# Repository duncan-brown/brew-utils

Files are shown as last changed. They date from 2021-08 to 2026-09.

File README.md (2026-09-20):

# brew-utils

Software for a homebrewery dashboard built out of Knight Rider (KITT) dash
replica hardware.

Two Raspberry Pis read temperature probes, flow meters, fermentation
controllers and a keg-monitoring database, and render all of it onto the gauges
of a replica KITT dashboard: the MPH display shows hot liquor tank temperature,
the RPM gauges show serving keezer probes, the LED bargraphs show fermenter
temperatures and how much beer is left in each keg, and the message center
captions whatever the multi-function display is currently showing.

There is a full build write-up, with photos of what every gauge means, at
[Brewery Dashboard on HomebrewTalk](https://www.homebrewtalk.com/threads/brewery-dashboard.726917/).
The physical side — power supply, relays, probes, which wire goes to which pin
on which Pi — is in [HARDWARE.md](HARDWARE.md).

## How it fits together

```
    probes, flow meters, kegs                two Raspberry Pis            KITT dash
    ─────────────────────────                ─────────────────            ─────────
    DS18B20 one-wire probes  ──────────────▶  rpints  ──── serial ────▶  tacho
    RaspberryPints (MySQL)   ──────────────▶          ──── serial ────▶  dummy3, dummy6
                                                 │
                                            GPIO │ mode
                                                 ▼
    DS18B20 one-wire probes  ──────────────▶  brewpi  ──── serial ────▶  speedo
    BrewPi Remix ◀── TiltBridge ◀── Tilt ──▶          ──── serial ────▶  message center
    flow meter relays        ◀──────────────
```

- **`rpints`** runs [RaspberryPints](https://github.com/RaspberryPints/RaspberryPints)
  for keg volume tracking, and owns the dashboard's Power/Auto/Norm/Pursuit
  buttons and the power relays for the whole dash.
- **`brewpi`** runs three instances of [BrewPi Remix](https://github.com/brewpi-remix/brewpi-tools-rmx)
  for fermentation control, which get specific-gravity readings from Tilt
  hydrometers via [TiltBridge](https://github.com/thorrak/tiltbridge).
- The two Pis coordinate over GPIO lines so that pressing Auto, Norm or Pursuit
  on one changes what the other displays and how brightly.
- Both drive the dash boards over serial using Paolo Sancono's KITT protocol.
  The dash electronics themselves are from [ideegeniali](https://www.ideegeniali.it/).

## What's in here

| Path | Status | Description |
| --- | --- | --- |
| [`kitt/`](kitt/) | **in service** | The current system. `panp/panp.py` drives the whole dashboard; `switchpod/` is the Arduino firmware for the dash keypads. See [kitt/README.md](kitt/README.md) for how it works, and [kitt/DASHBOARD.md](kitt/DASHBOARD.md) for what each gauge means. |
| [`schematics/`](schematics/) | reference | KiCad schematics of the control electronics, four sheets generated from the wiring in `HARDWARE.md`; rendered as `images/schematic-*.svg`. |
| `brewpitosmith` | utility | Converts a BrewPi Remix beer log into a CSV that BeerSmith 3 will import, thinned to one row an hour. |
| `images/` | reference | Photographs of the switch pods, the season 2 dash scan, and the `hw-*` photographs of the bench, supply box and control panel that [HARDWARE.md](HARDWARE.md) refers to. |

Two earlier efforts have been archived out of the tree. Each is tagged, so the
whole thing comes back with one command:

| Tag | What it was |
| --- | --- |
| `karr-prototype` | An attempt to rebuild the dash electronics from scratch — four ESP32s driving daisy-chained TLC5940 drivers, with a KiCad board and gerbers. Shelved in 2023 when the ideegeniali boards arrived; never ran the brewery. |
| `pi-temp-display-final` | The predecessor to the KITT dash: seven-segment LEDs multiplexed with pigpio, showing mash temperature and keezer min/max. |

```bash
git checkout karr-prototype -- karr/
```

## Credits

The parts of this system that do the actual work of running the brewery are
other people's: BrewPi Remix by [@LBussy](https://github.com/lbussy), TiltBridge
by [@Thorrak](https://github.com/thorrak), RaspberryPints by
[@RandR+](https://github.com/RandRPints), and the KITT dash boards and serial
protocol by Paolo Sancono at ideegeniali. Thanks also to @day_trippr for help
along the way.

## License

MIT — see [LICENSE](LICENSE).

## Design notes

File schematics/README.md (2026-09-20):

# Schematics

KiCad schematics of the brewery control electronics, generated from the wiring
recorded in [../HARDWARE.md](../HARDWARE.md). Four sheets, A3:

| Sheet | File | What is on it |
| --- | --- | --- |
| 1 | `sheet1-power.kicad_sch` | the supply box: 12 V supply, the three inline fuses, the latching relay and the two Pi interlocks behind the `POWER` button, both D-1012 contactors, the D-1384 fuse block, the 12→24 V converter and the buffer capacitor |
| 2 | `sheet2-rpints.kicad_sch` | rpints: PANP buttons and lamps, the 8-way relay module (flow meters and lamps), the 4-channel dash power module, the serving keezer strip and RaspberryPints Uno, the 12-way serial/one-wire strip, the right switch pod |
| 3 | `sheet3-brewpi.kicad_sch` | brewpi: relay drives, mode lines, hot-side probes, serial to the message centre and speedo, the left switch pod, and the three BrewPi Remix controllers with their heaters and glycol pumps |
| 4 | `sheet4-dash.kicad_sch` | strip 1 to the Pi buck converters, the DASH POWER block to the six dash boards, and the four PANP switches on their two 8-way strips |

Rendered copies are in [`../images/`](../images/) as `schematic-sheet*.svg`.

## How they are made

The sheets are **generated**, not drawn by hand. `ksheets.py` describes every
component and wire in Python; `kicadgen.py` turns that into KiCad's S-expression
format (version `20250114`, KiCad 9 and 10). Stock symbols such as fuses,
resistors and screw terminals are copied out of the installed KiCad libraries at
generation time; the relay modules, Pis, Unos and dash boards are simple boxes
with named terminals defined in `kicadgen.box_symbol`, which is how they present
physically.

Nets that cross sheets are global labels with the same name on each sheet, for
example `MASTER_RELAY`, `P1_+12V`, `RPINTS_GND`, `BREWPI_IO16`.

To regenerate after editing `ksheets.py`:

```bash
python3 schematics/ksheets.py schematics
```

then export and check with KiCad's command line:

```bash
K=/Applications/KiCad/KiCad.app/Contents/MacOS/kicad-cli
for f in schematics/sheet*.kicad_sch; do
  $K sch export svg -o images -e "$f"
  $K sch erc --severity-all --format report -o "${f%.kicad_sch}.erc" "$f"
done
```

All four sheets pass ERC with no errors. The remaining warnings are expected:
global labels that appear on only one sheet (they are for the reader, and for
the sheet they pair with), and the note that the home-made `brew:` symbols are
not in a configured library, which is by design since they are embedded in each
file.

## Editing in KiCad

The files open directly in KiCad's schematic editor. Edits made there are fine
for a one-off print, but they will be overwritten by the next run of
`ksheets.py`, so a lasting change belongs in the Python. The reference
designators are deliberate and match [../HARDWARE.md](../HARDWARE.md): `K1` is
the latching relay, `K2`/`K3` the interlocks, `K4`/`K5` the contactors, `K6` the
8-way module, `K7` the 4-channel dash power module, `K8` the 6-channel fermenter
module.

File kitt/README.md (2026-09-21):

# kitt

The software that drives the KITT dashboard. Two pieces:

- [`panp/panp.py`](panp/panp.py) — the daemon that runs on both Raspberry Pis
  and puts brewery data onto the dash gauges.
- [`switchpod/`](switchpod/) — Arduino firmware that reads the dash keypads.
  How a pod reaches the Pi is in [switchpod/README.md](switchpod/README.md).

PANP stands for Power / Auto / Norm / Pursuit, the four buttons on the dash.

This file is about how the software works. For what each gauge on the dash
means — KITT's labels against the brewery values behind them — see
[DASHBOARD.md](DASHBOARD.md).

## One script, two Pis

`panp.py` is installed identically on both machines and decides what it is at
startup from `socket.gethostname()`. Anything else exits with an error.

| | `rpints` | `brewpi` |
| --- | --- | --- |
| Loop class | `RPintsLoopHandler` | `BrewPiLoopHandler` |
| Reads | 6 keezer + 3 lager probes, RaspberryPints MySQL | mash + HLT probes, 3 BrewPi Remix instances |
| Drives | tacho, red dummy3, dummy6 | speedo, message center, red/green dummy3 |
| Owns | PANP buttons and lamps, dash power relays, the Hue bench and room lights | flow meter relays |
| Mode GPIO | output (tells `brewpi` the mode) | input (follows `rpints`) |

Shared between them: `read_probe_f` and the `get_temps` thread,
`BrightnessHandler`, `Bus` and `Wire` (the serial ports and the gate that
paces writes to them), `Service` (systemd
notification and shutdown), and the pin constants at the top of the file.
`main()` calls `setup_rpints` or `setup_brewpi` and then runs the loop.

## Structure

Everything slow runs in a daemon thread and communicates with the main loop
through a `Queue`. The main loop never blocks on I/O.

```
  ┌────────────────────┐
  │ get_switchpod()    │  reads /dev/switchpod, one digit per keypress
  ├────────────────────┤
  │ get_temps()        │  polls one-wire probes once a second
  ├────────────────────┤        ┌───────────┐      ┌──────────────┐
  │ get_brewpi_rmx_... │───────▶│  Queues   │─────▶│ loop_handler │────▶ serial
  └────────────────────┘        └───────────┘      │  .loop()     │      to dash
                                                   └──────────────┘
                                                    every 0.25 s
```

Each `loop()` call drains its queues with `drain(q)`, recomputes what should
be on screen, and writes it out. Queue entries are `(index, value)` tuples.

The Hue lights run the other way round: `PANPHandler` queues an on or off
request for the bench light from the button callback, the loop handler
queues one for the room lights when a right-pod key asks, and the
`HueLight.loop()` thread talks to the Hue bridge, which is in another part of
the building. A slow or absent bridge can therefore never hold up the dash.

The database is polled less often than everything else: `RPintsLoopHandler`
counts passes and only queries RaspberryPints once every `DATABASE_EVERY`
passes, which is eleven.

## The PANP modes

Pressing a PANP button on `rpints` moves power relays and flips the two GPIO
lines that `brewpi` watches, so both Pis change behaviour together.

| Mode | Dash | Message center |
| --- | --- | --- |
| **Auto** | off (relays cut power to upper and lower dash) | stays on, showing `BREWPI UP` and flow meter status |
| **Norm** | on, dimmed | captions the lower display |
| **Pursuit** | on, full brightness, switch pod lamps lit, bench light on | captions the lower display |

Leaving Auto clears every display and re-sends brightness, because the boards
were unpowered and have lost their state.

Pursuit also switches on the Hue light strip over the brewery workbench, at
full brightness and a chosen white, so there is enough light to read small
print; Norm and Auto switch it off, as does halting the Pis. Two keys on the
right switch pod, `P IND` and `EJECT R`, switch the brewery's room lights on
and off the same way. `rpints` talks to the Hue bridge's v2 API directly, from
a worker thread. It is optional and is configured by
`/usr/local/etc/panp-hue.json`, which is not in this repository because it
holds the bridge's application key; without the file nothing happens, which
is the case on `brewpi`. Setting it up, including getting a key from the
bridge, choosing the colour temperature and listing the room lights, is in
[panp/README.md](panp/README.md).

The Power button is not software at all. It triggers a latching relay that
switches the whole 12 V supply, and each Pi holds an interlock relay *open*
while it is up, taking the button out of the circuit — so nothing can be
switched off without halting both Pis first. That is `power-relay-*.service`
(opens the interlock at boot) and `power-off-*.sh` (releases it during
shutdown). The wiring is in [../HARDWARE.md](../HARDWARE.md#the-power-button).

## Switch pod buttons

Each switch pod is a resistive keypad read by an Arduino, which prints a
position 0–9 over serial; `panp.py` reads them from `/dev/switchpod` in
`get_switchpod()` and queues them for the loop handler.

Even positions are the pod's left column, odd positions the right — which is
why each handler treats `sp_val` 0/2/4/6/8 as one family and 1/3/5/7/9 as
another. The **right** pod (`rpints`) drives the tacho digits and arc: its
left column is one key per keg, showing the imperial pints left and then the
US gallons left before returning to the keezer mean, its right
column shows the three lager probes, and its last two keys switch the brewery
room lights over the Hue bridge — except that in Pursuit `P IND` cycles the
bench light's colour instead. Coming up from Auto resets the tacho to the
mean. The **left** pod (`brewpi`) selects what the lower speedo display shows
and toggles the flow meter relays. Toggling a flow meter flashes `FLOW n on` on
the message center for a second, then restores the normal caption.

Full button-by-button tables, with photographs of both pods, are in
[DASHBOARD.md](DASHBOARD.md).

## Talking to the dash

The boards are serial slaves at 57600 baud on `/dev/ttyAMA0` and `/dev/ttyAMA1`,
addressed by a letter — `A` tacho, `B` speedo, `C` message center, `E`/`F`
dummy3, `G` dummy6. A command looks like:

```
>ABp3C?
 │││ └── payload: hex byte pairs
 ││└──── register: which value on that board
 │└───── command: B write byte, H write hex sequence, S write string
 └────── destination board
```

so `>ABp3C?` means "tacho, write byte, register p (the seven-segment value),
0x3C". Values are scaled to bytes before sending — `tacho_bar`, `lager_bar`,
`keg_bar` and `temperature_bar` map a temperature or a percentage onto the
bargraph steps by walking a list of thresholds, which is where the dash gets
tuned.

The protocol is Paolo Sancono's and the full specification comes with the
boards — but note that the tacho and speedo registers this code writes are
**not in that specification**. The shipped firmware could not set those displays
from a host at all, so in 2023 the commands were added to it: user-value
registers for the tacho's bars and seven-segment, and for the speedo's two
bargraphs and both digit groups. Paolo holds that modified firmware and is free
to ship it. When one of these commands needs checking, the board firmware is the
authority, not the protocol PDF.

That firmware is confidential to Paolo and is not in this repo. Keep it that
way: describing what a command *does* is fine, quoting or paraphrasing his
source is not.

Two things worth knowing before editing the serial code:

- **Every write is preceded by a 0.1 s gap, and a Pi sends one packet at a
  time across both of its buses.** Without the gap the boards drop messages;
  and the two buses share a level shifter that corrupts a packet on one when
  the other is transmitting. Both rules live in `Bus.write`, which takes a
  first-come-first-served turn on the shared `Wire`, so every write gets the
  gap and a burst from one thread cannot starve the other.
- **Hex payloads must be exactly the right length** — four byte pairs for the
  speedo's upper digits, five for the lower, one per bar for the bargraphs.
  A payload of the wrong length is ignored silently rather than rejected.

## The BrewPi side

The fermenter temperatures and Tilt gravities come from three BrewPi Remix
instances on `brewpi`, in `/home/brewpi/{unitank-1,unitank-2,chronical}/`.
`get_brewpi_rmx_data()` asks each one `lcd` and `statusText` every 60 seconds
over a Unix socket called `KITTSOCKET` in the instance directory.

Stock BrewPi Remix has no such socket. It listens on one, `BEERSOCKET`, for its
own PHP front end. `KITTSOCKET` comes from the **`kitt` branch** of
[duncan-brown/brewpi-script-rmx](https://github.com/duncan-brown/brewpi-script-rmx),
commit `7e0e500` "open a second socket for kitt" (April 2023) and two
follow-ups, and that branch is what the Pi runs. The change:

- pulls the socket setup into a helper and calls it twice, so `KITTSOCKET` is
  created next to `BEERSOCKET` with the same `brewpi:www-data` ownership and
  `0660` mode;
- makes the main loop **alternate** between accepting on the PHP socket and the
  KITT socket, one per pass, so neither client can starve the other. Whichever
  connects is served by the same command handler, so the dash could ask for
  anything the web UI can;
- halves the socket timeout from 0.5 s to 0.25 s so the controller is still
  polled as often with two accepts sharing the loop, and replaces the
  `raise socket.timeout` trick for "go and do serial now" with an explicit
  `SerialExpected` exception.

A separate socket rather than sharing `BEERSOCKET` keeps the dash's polling
from ever queueing behind the web UI's, and vice versa.

**Known state, September 2026.** The `kitt` branch forked from `main` in 2021
and is ten commits behind it. In particular it lacks `9aabb93` "expire the
correct tilt color" (2022), which sets the colour from the config before
clearing a stale TiltBridge reading; without it that code path uses an
undefined name. On the Pi, `unitank-2`'s copy of `brewpi.py` carries an
uncommitted `color = 'Green'` at that point — the same fix done by hand for its
own Tilt — and `unitank-1` has a commented-out `# color = 'Blue'`. The clean fix
is to merge `main` into `kitt`, or cherry-pick `9aabb93`, redeploy all three
instances and drop the local edits. Until then, anyone reinstalling from either
branch as-is gets different behaviour from what is running.

## Installation

There is nothing to build. On each Pi:

```bash
sudo install -m 755 panp/panp.py /usr/local/sbin/panp.py
sudo install -m 644 panp/panp.service panp/panp.path /usr/local/lib/systemd/system/
sudo install -m 644 panp/power-relay-<host>.service /usr/local/lib/systemd/system/
sudo install -m 755 panp/power-off-<host>.sh /lib/systemd/system-shutdown/
sudo systemctl enable panp.path power-relay-<host>.service
```

`panp.path` lists `/dev/switchpod`, `/dev/ttyAMA0` and `/dev/ttyAMA1`. Note
that systemd fires a path unit when **any** of its conditions is met, not all
of them, and the two UARTs exist from early boot — so in practice the service
starts as soon as the UARTs appear, whether or not the switch pod adapter is
there yet. That is harmless: `get_switchpod()` waits for `/dev/switchpod` to
appear and reopens it if it goes away. The service is `Type=notify` and
reports progress through sdnotify, so `systemctl status panp` shows what it is
doing.

Requires Python 3 with `pyserial`, `sdnotify`, `RPi.GPIO` and
`mysql-connector-python`. The switch pod's serial adapter needs to appear as
`/dev/switchpod`, which takes a udev rule — not included here.

## Notes

- `RPintsLoopHandler` computes `keezer_min`, `keezer_max` and `keezer_median`
  every pass, but no switch pod button currently selects them — only the
  individual probes, the lagers and the mean are reachable.
- The code that cycled fermenter status (`IDLE`/`COOL`/`HEAT`) on the message
  center was commented out for years and has been removed, along with the
  queue that fed it. In Auto the message center shows `BREWPI UP` instead.
  The old code is in git history at `9f49075`.
- Entering Auto puts the lower display into `BREWPI_UP` mode and remembers
  what was selected; leaving Auto restores it, so the caption and the value
  under it agree. A left-pod press while the dash is dark takes effect
  instead when it comes back. The caption itself is always written by the
  main loop, never by the GPIO callback: the loop may still be finishing a
  dark pass, and its trailing override-off packet would lapse a caption sent
  from the callback straight back to the rotation.
- A one-wire read that fails, or fails its CRC, is skipped and the display
  keeps the last good value. The hot-side line hiccups for a second every so
  often and both probes on it come back empty together, which used to paint
  `000` on the speedo. After ten failures in a row the probe is shown as 0.0
  so a probe that has really gone is still visible.
- Exception handling is deliberately broad. This is an unattended daemon with
  `Restart=no`; a probe that fails to read or a database that is down must not
  take the dashboard down with it.

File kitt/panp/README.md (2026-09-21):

# Hue lights over the bridge

`rpints` drives two things on the house's Hue bridge, which is in another
part of the building, over WiFi:

- **The bench light.** Pursuit switches the Hue lightstrip over the brewery
  workbench on at full brightness and a chosen white, so there is enough
  light to read small print; Norm and Auto switch it off, as does halting the
  Pis. On the bridge it is named "Brewery Bench Light". Do not confuse it with
  "Brewery Lightstrip", a second strip round the back of the workbench that
  HomeKit and a Hue motion sensor look after and `panp.py` never touches.
- **The room lights.** In Auto or Norm, `P IND` on the right switch pod
  turns the brewery's room lights on at a set brightness and `EJECT R` turns
  them off. Which lights are in that set is a list in the config file; the
  bench light and the motion-sensor lightstrip are deliberately not in it.
  See "Room lights" below.
- **The bench light's colours.** In Pursuit, with the bench light already
  on, `P IND` steps it round a cycle of colours and back to its normal white.
  See "Bench light colours" below.

It is optional. `panp.py` looks for `/usr/local/etc/panp-hue.json` and does
nothing at all if it is absent, which is the case on `brewpi`. Nothing needs
installing — it uses `urllib.request` and `ssl` from the standard library, and
talks to the bridge's v2 API directly rather than going through HomeKit. The
bridge is what Home talks to anyway, so Home follows along.

The config file is **not** in this repository, because the key it holds grants
full control of every light on that bridge. See
[panp-hue.json.example](panp-hue.json.example) for the shape.

## Getting the bridge address

The discovery service returns the bridges on your network:

```bash
curl -s https://discovery.meethue.com
```

Confirm which is which — the `name` field is whatever you called it in the Hue
app, and `modelid` must be `BSB002` for HomeKit to be involved at all:

```bash
curl -s http://BRIDGE_IP/api/0/config
```

Run this from the Pi that will drive the light, not from a laptop. It doubles as
proof the Pi can reach the bridge, which is the link that actually has to work.

## Getting an application key

The bridge grants a key only to someone who can physically press its button.
Start this first, then go and press the round button on top of the bridge — it
polls for two minutes so there is no 30 second window to hit:

```bash
for i in $(seq 1 60); do r=$(curl -s -X POST http://BRIDGE_IP/api -d '{"devicetype":"panp#rpints"}'); case "$r" in *username*) echo "$r"; break;; esac; sleep 2; done
```

Before the button is pressed each attempt returns `link button not pressed`.
After it, you get `{"success":{"username":"..."}}`. That 40-character string is
the key. Treat it as a password: it is permanent until deleted and it controls
every light on the bridge.

## Finding the light id

The v2 API addresses lights by UUID:

```bash
curl -sk -H "hue-application-key: YOUR_KEY" https://BRIDGE_IP/clip/v2/resource/light
```

`-k` is needed because the bridge serves a self-signed certificate. Find the
light you want by `metadata.name` and take its `id`.

## Installing

```bash
sudo install -m 600 -o root -g root /dev/null /usr/local/etc/panp-hue.json
```

Fill it in following the example, then:

```bash
sudo systemctl restart panp
```

`systemctl status panp` then reports either `has a bench light` or `has no bench
light configured`, so a typo in the json shows up immediately rather than
silently doing nothing.

## Tuning

`brightness` is a percentage. `mirek` is colour temperature, and it is the
reciprocal of Kelvin — **lower is colder**:

| mirek | ≈ Kelvin | |
| --- | --- | --- |
| 153 | 6500K | coldest most Hue fixtures manage |
| 200 | 5000K | daylight, can read clinical |
| 250 | 4000K | neutral |
| 300 | 3300K | warm neutral |
| 366 | 2730K | the Hue default warm white |
| 500 | 2000K | candle-ish |

Check the fixture's own range first — `mirek_schema` in the light resource above
gives its minimum and maximum.

Both values are in the config file rather than in the code so the light can be
tuned without editing a public repository. **The config is read once at
startup**, so restart the service after changing it. And note that `panp.py`
sets brightness and colour temperature explicitly on every Pursuit press, so
adjusting that light by hand in the Hue app will not survive the next press —
the config wins.

## Room lights

The `room` block lists the lights the two right-pod keys switch, by v2 id
from the same listing as above, and the brightness to switch them on at:

```json
"room": {
  "brightness": 100,
  "lights": ["0dd1d1b9-...", "23edba6e-...", "..."]
}
```

Each key press sends one request per light from the worker thread, so a dozen
lights take a second or so to all change and the dash never waits. Only the
on/off state and brightness are sent; colour temperature is left as the Hue
app or a scene last set it. If several presses pile up while the bridge is
slow, only the last one is sent. Leaving the block out disables the two keys
and they do nothing.

Rooms and zones would let one request switch a whole group, but the brewery
room on the bridge also contains the bench light and the lightstrip, which
must not follow these keys, so the lights are listed individually.

## Bench light colours

In Pursuit the bench light is on in its normal white, and `P IND` steps it
through a cycle; the press after the last colour returns to normal, and
every entry into Pursuit starts the cycle over. The default cycle is warm
white, red, purple, pale blue. To change it, add a `bench_cycle` list to the
config, one entry per press, each either a colour temperature or a CIE xy
colour:

```json
"bench_cycle": [
  {"mirek": 450},
  {"xy": [0.68, 0.31]},
  {"xy": [0.30, 0.13]},
  {"xy": [0.24, 0.27]}
]
```

The list can be any length. Brightness stays at the config's `brightness`
throughout. Hue's xy is the CIE 1931 chromaticity the bridge uses for
colour; the strip clamps anything outside its gamut to the nearest colour it
can make, so approximate values are fine. Rough landmarks: red about
(0.68, 0.31), green (0.17, 0.70), blue (0.15, 0.06), and whites near
(0.31, 0.33); moving toward the white point makes a colour paler.

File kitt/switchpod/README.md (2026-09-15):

# switchpod

Firmware for the Arduinos that read the dash switch pods.

Each Pi has its own pod and its own Arduino running this same sketch: the right
pod on `rpints`, the left pod on `brewpi`. Which buttons do what is in
[../DASHBOARD.md](../DASHBOARD.md).

## How a pod is read

A pod is ten buttons wired as a **resistive ladder** brought out on a single
signal wire. Each button switches a different resistor — 1k, 1k2, 1k5, 1k8,
2k2, 2k7, 3k3, 3k9, 4k7, 5k6 — so pressing one produces a distinct voltage and
the whole pod costs one ADC channel instead of ten digital inputs.

Wiring is three conductors: the pod's `SGN` to an analog pin, ground common
between pod and Arduino, and a **pull-up resistor from `SGN` to +5V** (to 3V3
instead on a 3.3V board). Paolo's recommendation is 3k3, sitting in the middle
of the ladder's span for the best noise margin. With nothing pressed the pin
floats up to the rail and reads about 1023; each button pulls it down to its own
level.

`readSwitchpod()` reads the ADC and bins the result:

| ADC reading | Position |
| --- | --- |
| ≤ 421 | 0 |
| 422–463 | 1 |
| 464–507 | 2 |
| 508–549 | 3 |
| 550–595 | 4 |
| 596–640 | 5 |
| 641–680 | 6 |
| 681–717 | 7 |
| 718–751 | 8 |
| 752–895 | 9 |
| > 895 | nothing pressed |

Resting state is the top band — the line idles pulled high, and pressing a
button drags it down. Position 0 sits at the bottom of the ladder and gets the
whole range below 421.

**Positions are physical, not logical**: even positions run down the left column
of the pod, odd positions down the right. So position 0 is top left, 1 is top
right, 2 is second left, and so on. That is why `panp.py` handles `sp_val` 0, 2,
4, 6, 8 as one family of actions and 1, 3, 5, 7, 9 as another — the two columns
do different jobs.

If a button reads as its neighbour, the fix is to re-measure and adjust the
thresholds in `values[]` rather than to change anything on the Pi. Paolo's
calibration method: print `analogRead()` continuously, press each button in
turn, note the ten values, sort them, and set each threshold at the midpoint
between neighbours. The values in the sketch came from that exercise on these
pods and are not universal — a different pull-up moves all ten.

## Debounce and repeat

`readDebouncedSwitchpod()` requires the reading to stay put for **20 ms** before
accepting it, and gives up after **150 ms** if it never settles, returning "no
key". Contact bounce and the slew as your finger lands are both rejected.

`loop()` holds a `stoProcessando` flag so a key is reported **once per press**.
It will not repeat until the pod reads empty again, so holding a button down
does nothing more than tapping it.

## Wire format

9600 baud, 8N1, over the USB serial adapter. On a press the Arduino sends the
position as a single ASCII digit followed by a newline:

```
4\n
```

`panp.py` opens the adapter as `/dev/switchpod` (a udev rule maps it; not
included in this repo), reads a line at a time with `readline()`, strips the
newline, and pushes the integer onto a queue for the loop handler to act on.
(It used to read a fixed two bytes; the section below explains why that
changed.)

## The every-twentieth-press dropout, and why it took three changes

Worth reading before touching either side, because no one change here was wrong
on its own.

Paolo's example sketch separates keys with a **space** and wraps the line every
twentieth key, so a serial monitor stays readable:

```cpp
Serial.print(key);
Serial.print(" ");                        // "0 3 7 2 ..."
if ((aCapo % 20) == 0) Serial.println();  // wrap every 20 keys
```

**Change one:** this sketch made the separator `"\n"` so each key arrives on its
own line for parsing. At that moment the wrap stopped being a wrap and became a
stray empty line — a bare `Serial.println()` writes `\r\n`.

It still cost nothing, because the original reader on the Pi was

```python
data = state.decode().strip()
if data:
    sp_q.put(data)
```

which quietly dropped the empty line.

**Change two:** the `restart switchpod on error` commit (March 2024) replaced
that with a parse and a reopen, so unreadable input would re-establish the port
instead of being ignored. That was aimed at genuine flakiness on the wire — but
it also removed the `if data:` guard. From then on the routine twentieth-press
newline parsed as an empty string, raised, and triggered a full
close-and-reopen. The pod went deaf for about three seconds every twenty
presses, for two years.

**Change three**, the fix, is on both sides:

- The firmware no longer emits the wrap. One key, one line, nothing else.
- `get_switchpod()` skips empty lines *and* still reopens the port on anything
  it genuinely cannot parse, so the flaky-wire recovery survives.

The Pi also reads with `readline()` rather than a fixed two bytes, which matters
for the flaky case specifically. With fixed-size reads one stray byte shifts the
framing permanently — every later read straddles two presses and yields nonsense
until something triggers a reopen, so a single glitch looks like total failure.
Reading line-wise resynchronises at the next newline, so a glitch costs one
keypress. If you ever see garbage that does *not* recover, suspect a burst with
no newline in it at all, which will sit in `readline()` until one arrives.

Keeping the host-side skip after fixing the firmware is deliberate: an Arduino
that has not been reflashed, or one flashed from an older checkout, still works.

## Building

PlatformIO, targeting an Arduino Uno:

```bash
pio run -t upload
```

The pods came from ideegeniali with the dash, and this sketch is Paolo's
key-reading code with two changes. His original reads **two** pods from one
Arduino — `A0` and `A1`, reporting 0–19 with the right-hand pod offset by ten.
Here each pod has its own Arduino reading `A0` alone and reporting 0–9, because
the two pods are wired to different Raspberry Pis. The other change is the
separator, described above.

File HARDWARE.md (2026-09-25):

# The brewery hardware

What the software in this repository is wired to. [kitt/README.md](kitt/README.md)
explains how `panp.py` behaves and [kitt/DASHBOARD.md](kitt/DASHBOARD.md) what the
gauges mean; this file is the physical side — what is powered from where, which
wire goes into which pin, and which box does which job.

Everything here was read off the running Pis, the code, and the photographs in
the [build thread](https://www.homebrewtalk.com/threads/brewery-dashboard.726917/),
then walked terminal by terminal with the owner in September 2026. The few
things not yet checked are marked **(confirm)** and listed again under
[Still to confirm](#still-to-confirm) at the end.

## The shape of it

The brewery splits into a hot side and a cold side that share almost nothing but
a room. The hot side is a three-vessel HERMS built to
[The Electric Brewery](https://shop.theelectricbrewery.com/) design; its control
panel is self-contained and documented there, and it touches the rest of this
system only through two temperature probes. The cold side — three fermenters, a
lagering keezer, a serving keezer with five taps — is where all the control
electronics live, and the KITT dash is the front panel for it.

```
                12 VDC 30 A supply ─┬─▶ dash boards (via power relays)
                                    ├─▶ fermenter heaters (via BrewPi relays)
                                    ├─▶ 12→24 V converter ─▶ glycol pumps (via BrewPi relays)
                                    ├─▶ 12→5 V converters ─▶ the two Pis
                                    └─▶ relay modules, PANP lamps

   HOT SIDE                         CONTROLS                        COLD SIDE
   ─────────                        ────────                        ─────────
   mash tun probe ──┐                                     ┌── 3× Arduino Uno ─── fermenter probe,
   HLT probe ───────┴─ 1-wire ──▶  brewpi Pi 4  ◀── USB ──┤   (BrewPi Remix)     heat relay, cool relay
                                    │  │  │               └── Arduino Uno ─── left switch pod
                                    │  │  └── 5 relays ──▶ flow meters
                                    │  └── serial ──▶ speedo, message centre, dummy3 F
                                    │ 2 GPIO lines (mode)
                                    ▼
   6 keezer probes ─ 1-wire ──▶  rpints Pi 4  ◀── USB ──┬── Arduino Uno ─── 5× SF800 flow meters
   3 lager probes ── 1-wire ──▶     │  │                └── Arduino Uno ─── right switch pod
                                    │  └── serial ──▶ tacho, dummy6, dummy3 E
                                    └── PANP buttons/lamps, dash power relays

   Tilt ×3 ──▶ TiltBridge ── WiFi ──▶ brewpi          Hue bridge ◀── WiFi ── rpints
```

Independent of all of it: a Johnson Controls A419 on each keezer holds the
temperature. The Pis only *watch* the keezers; they never control them.

## Block diagrams

The same system, five ways. GitHub renders these; the ASCII sketch above is the
fallback for anything that does not.

### Power

Everything on the 12 V side, from the wall to the loads. Fuse values are the
ones fitted; the contactors are the two D-1012s in the supply box.

```mermaid
flowchart TB
  mains["Mains 120 V"] --> psu["12 V 30 A switching supply<br/>(gutted CCTV box)"]

  subgraph box["Supply box"]
    direction TB
    psu --> f3["3 A inline"] --> latch["HiLetgo latching relay<br/>trigger: POWER button via two Pi interlocks"]
    latch -- "NC output · 'master relay'" --> k1["D-1012 lower contactor"]
    latch -- "NC output" --> k2["D-1012 upper contactor"]
    psu --> k1 --> fb["D-1384 fuse block · 6 × ATO"]
    psu --> f25a["25 A inline"] --> mggi["MGGi 12→24 V boost<br/>15 A · 360 W"]
    k2 --> f25b["25 A inline"] --> cap["Belva BB1D 1 F<br/>buffer capacitor"]
    cap -. "parallel across<br/>converter input" .- mggi
  end
  latch --> plamp["POWER button lamp"]

  subgraph panel["Control panel"]
    direction TB
    fb -- "V1 · 7.5 A · 'P1'" --> s1["strip 1 · switched 12 V"]
    fb -- "V2 · 5 A · 'DASH POWER'" --> dp["DASH POWER block"]
    fb -- "V3 V4 V5 · 7.5 A each" --> s2["strip 2 · heater feeds"]
    mggi --> s3["strip 3 · 24 V"]
    s1 --> buck["2 × SSLHONG 12→5 V USB-C"]
    s1 --> lamprel["8-way relay module · ch 6–8"]
    dp --> r4["SunFounder 4-ch relay module"]
    s2 --> r6h["6-ch relay module · relays 1–3"]
    s3 --> r6c["6-ch relay module · relays 4–6"] --> s4["strip 4"]
  end

  buck --> pis["rpints Pi 4 · brewpi Pi 4"]
  lamprel --> lamps["AUTO · NORM · PURSUIT lamps"]
  r4 --> dashloads["ch 1 'SPEED' → switch pod lamps<br/>ch 2 'TACHO' → speedo · tacho · dummy6<br/>ch 3 'DUMMY3' → dummy3 E · dummy3 F<br/>ch 4 'COMM' → message centre"]
  r6h --> heat["3 × FTSs heater pads · 12 V<br/>cables H1–H3"]
  s4 --> pumps["3 × Penguin XL glycol pumps · 24 V"]
```

### Controllers and relays

The two Pis, the six Unos, and which relay module each one drives. Sensors are
in [Sensor buses](#sensor-buses) and the dash serial in
[Dash serial](#dash-serial).

```mermaid
flowchart LR
  subgraph IN["inputs"]
    direction TB
    btns["PANP buttons<br/>AUTO NORM PURSUIT"]
    podR["right switch pod"] --> unoSR["Uno · right pod"]
    podL["left switch pod"] --> unoSL["Uno · left pod"]
    unoR["Uno · RaspberryPints sketch<br/>flow meter pulses"]
    unoF["3 × Uno · BrewPi<br/>unitank-1 · unitank-2 · chronical"]
    tb["TiltBridge"]
  end

  subgraph RP["rpints · Raspberry Pi 4 · 10.0.1.31"]
    direction TB
    panpR["panp.py<br/>RPintsLoopHandler"]
    rpdb["RaspberryPints<br/>MariaDB + web"]
  end
  subgraph BP["brewpi · Raspberry Pi 4 · 10.0.1.32"]
    direction TB
    panpB["panp.py<br/>BrewPiLoopHandler"]
    bpx["3 × BrewPi Remix"]
  end

  subgraph OUT["relay modules and outputs"]
    direction TB
    r8L["8-way relay module ch 6–8<br/>→ PANP lamps"]
    r4["SunFounder 4-ch<br/>→ dash power"]
    r8F["8-way relay module ch 1–5<br/>→ flow meter pulse lines"]
    r6["6-ch relay module<br/>→ heaters · glycol pumps"]
    interlock["2 × interlock relays<br/>in the POWER button chain"]
    hue["Hue bridge · bench light"]
    kiosk["kiosk browser<br/>http://10.0.1.31/"]
  end

  btns -- "GPIO 5 · 6 · 16" --> panpR
  unoSR -- USB --> panpR
  unoR -- USB --> rpdb
  unoSL -- USB --> panpB
  unoF -- USB --> bpx
  tb -.-> bpx
  bpx -- "KITTSOCKET" --> panpB
  panpR == "GPIO 7 · 22<br/>mode lines" ==> panpB

  panpR -- "GPIO 19 · 20 · 12" --> r8L
  panpR -- "GPIO 17 · 18 · 10" --> r4
  panpB -- "GPIO 16" --> r4
  panpB -- "GPIO 2 · 3 · 27 · 21 · 13" --> r8F
  unoF -- "pins 5 · 6" --> r6
  panpR -. "IO23, via systemd" .-> interlock
  panpB -. "IO5, via systemd" .-> interlock
  panpR -.-> hue
  rpdb -.-> kiosk
```

### Dash serial

Two buses per Pi, each through a TXS0108E level shifter with its `OE` on
GPIO 25, transmit only.

```mermaid
flowchart LR
  subgraph RP["rpints"]
    r0["ttyAMA0 · GPIO 14 TXD"]
    r1["ttyAMA1 · GPIO 8 CE0"]
  end
  subgraph BP["brewpi"]
    b0["ttyAMA0 · GPIO 14 TXD"]
    b1["ttyAMA1 · GPIO 8 CE0"]
  end
  r0 --> shR["TXS0108E"] --> E["E · red dummy3"] --> G["G · dummy6"]
  r1 --> shR --> A["A · tacho"]
  b0 --> shB["TXS0108E"] --> C["C · message centre"]
  b1 --> shB --> B["B · speedo"] --> F["F · red/green dummy3"]
```

### The POWER button

Why the button does nothing while a Pi is up, and why the system comes back on
its own after an outage.

```mermaid
flowchart TB
  btn["POWER button · C and NO"] --> i1["rpints interlock relay · NC contact<br/>held open by IO23 while rpints is up"]
  i1 --> i2["brewpi interlock relay · NC contact<br/>held open by IO5 while brewpi is up"]
  i2 --> trig["latching module · trigger input"]
  trig -. "each press toggles" .-> latch["latching module<br/>unlatched at power-up"]
  latch -- "NC output closed while unlatched" --> coils["D-1012 coils × 2"]
  coils --> rail["switched 12 V rail<br/>fuse block → strips → Pis · dash · heaters"]
  rail --> boot["Pis boot · power-relay-*.service<br/>drives IO23 and IO5 high"]
  boot -. "opens both interlocks" .-> i1
  halt["sudo halt on both Pis<br/>power-off-*.sh drives the pins low"] -. "closes both interlocks" .-> i1
```

### Sensor buses

Every one-wire bus and what pulls it up.

```mermaid
flowchart LR
  subgraph K["serving keezer — one 8-core cable"]
    kp["6 × DS18B20 · 5 V from the rpints Uno"]
    sf["5 × SF800"]
  end
  kp -- "data" --> k3["3-way block<br/>2.2 kΩ to Uno 3V3"] --> rp4["rpints GPIO 4"]
  sf -- "5 pulse lines" --> rel8["8-way relays 1–5"] --> unoR["rpints Uno pins 6–10"]

  lp["3 × DS18B20 · lagering keezer<br/>parasite powered"] -- "data" --> s12a["12-way strip 7<br/>2.2 kΩ to Uno 3V3 on 8"] --> rp26["rpints GPIO 26"]
  hp["2 × DS18B20 · mash tun and HLT thermowells<br/>parasite powered"] -- "data" --> s12b["12-way strip 10<br/>2.2 kΩ to brewpi 3V3 on 11"] --> bp4["brewpi GPIO 4"]

  fp["3 × DS18B20 · fermenter thermowells"] -- "data · 5 V · GND" --> s10["10-way strip<br/>4.7 kΩ to 5 V per probe"] --> unoF["BrewPi Unos · A0"]
  tilt["3 × Tilt · Red Green Blue"] -.-> tb["TiltBridge"] -. "WiFi" .-> bpx["BrewPi Remix"]
```

## Schematics

The wiring is also drawn as **KiCad schematics**, four A3 sheets in
[`schematics/`](schematics/), generated from the same facts as this file (see
[schematics/README.md](schematics/README.md) for how). Rendered copies:

| Sheet | Rendered | Covers |
| --- | --- | --- |
| 1 | [schematic-sheet1-power.svg](images/schematic-sheet1-power.svg) | the supply box and the `POWER` button circuit |
| 2 | [schematic-sheet2-rpints.svg](images/schematic-sheet2-rpints.svg) | rpints: PANP, dash power and flow-meter relays, keezer sensors, RaspberryPints Uno, right pod, serial to the tacho and dummies |
| 3 | [schematic-sheet3-brewpi.svg](images/schematic-sheet3-brewpi.svg) | brewpi: relay drives, hot-side probes, serial to the message centre and speedo, left pod, the three BrewPi controllers with heaters and pumps |
| 4 | [schematic-sheet4-dash.svg](images/schematic-sheet4-dash.svg) | strip 1 to the Pi converters, DASH POWER to the dash boards, the PANP switches on their strips |

Sheet 1 — the supply box and the POWER button

All four pass KiCad's electrical rules check with no errors. Where this file
and a sheet disagree, this file was walked with the owner and the sheet was
drawn from it, so fix the sheet.

## Power

Everything low-voltage runs from **one 30 A, 12 VDC switching supply**. It
started life as an InstallerCCTV **18-channel CCTV power distribution box**
(Amazon `B08XMKT1F8`, the 30 A variant of the listing, since discontinued): a
lockable, vented steel wall box holding a fan-cooled 360 W supply module and two
distribution boards with 18 PTC-fused screw-terminal outputs, 110–220 V AC in,
UL listed. **The distribution boards were stripped out** and only the enclosure
and the supply module kept. The box now holds, on DIN-style mounts above the
supply:

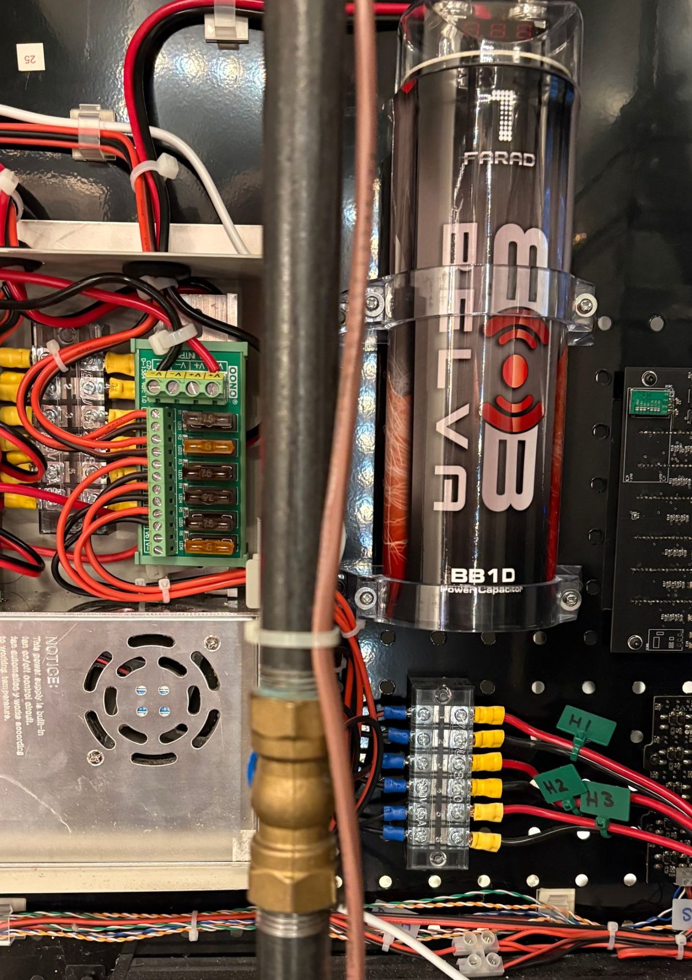
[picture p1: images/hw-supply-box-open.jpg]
Inside the supply box: contactors, fuse block and supply module, with the buffer capacitor and the heater block on the pegboard beside it


- **Two CZH-Labs D-1012 power relay modules** — single SPST-NO 30 A relay
  each, 12 V coil, with a red LED that lights when the coil is energised. Both
  coils are driven together by the latching module on the panel that the
  `POWER` button controls (see [The Power button](#the-power-button)), but they
  do different jobs: the **lower** contactor puts supply +12 V onto the D-1384
  fuse block and so onto the whole switched rail; the **upper** one connects
  the buffer capacitor described below, so that the capacitor is isolated when
  the system is off rather than left holding a charge across a dead rail.
- **A CZH-Labs D-1384 six-position fused distribution module** — 30 A in on a
  4-way terminal, six outputs each behind a medium ATO/ATC blade fuse (3 A as
  shipped, replaceable up to 10 A). Its +12 V input comes from the supply
  through the **lower D-1012 contactor**, and its 0 V goes straight back to the
  supply. The fused outputs leave the box as labelled cables:

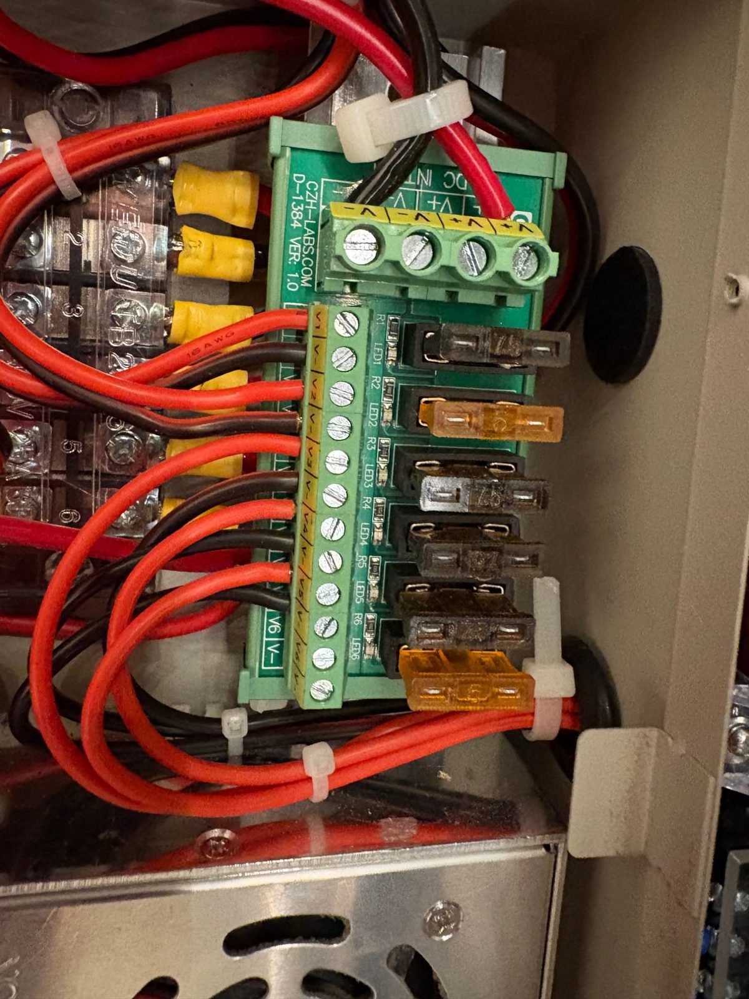
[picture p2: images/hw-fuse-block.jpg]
The D-1384 fuse block
  

  | Channel | Fuse | Feeds |
  | --- | --- | --- |
  | `V1` | 7.5 A | `P1` — distribution strip 1: the two Pi buck converters and the PANP lamps |
  | `V2` | 5 A | `DASH POWER` — the 4-way block feeding the dash power relays: every dash board and the switch pods |
  | `V3` | 7.5 A | heater H1, via distribution strip 2 and relay 1 |
  | `V4` | 7.5 A | heater H2, via strip 2 and relay 2 |
  | `V5` | 7.5 A | heater H3, via strip 2 and relay 3 |
  | `V6` | 5 A | not connected — spare |

  The heaters' 0 V returns come back to the fuse block's `V−` terminals. The
  module lights a per-channel LED when a fuse has blown. The fuses double as
  isolators: pull `V2` and every dash board goes dark while the Pis keep
  running; pull `V1` and both Pis lose power — a hard cut, so halt them first.
  The `master power` cable to the latching module is **not** on this block: it
  has to be live while the contactors are open, so it is taken off the rail
  ahead of them.
- **Three inline ATO blade fuse holders**, all fed straight from the supply's
  +12 V, ahead of the contactors:

  | Fuse | Feeds |
  | --- | --- |
  | 3 A | the `master power` cable — the latching module and, through it, both D-1012 coils. Unswitched, which is what lets the `POWER` button work at all |
  | 25 A | the 12 V input of the MGGi 12→24 V converter. Unswitched too, so the 24 V bus is live whenever mains is; the pumps themselves are switched by the BrewPi relays. This holder is hidden behind the D-1012s |
  | 25 A | from the upper D-1012 contact to the +12 V terminal of the buffer capacitor |

- **Two 6-way barrier strips** for bussing 12 V.

**The buffer capacitor.** A **Belva BB1D 1 farad car-audio power capacitor**,
the kind with a voltmeter in the top, is mounted on the back of the workbench
above the heater block, and through the upper contactor and its fuse sits in
parallel across the 12 V input of the 12→24 V converter. It is there because
the three **Penguin Chillers XL 24 V glycol pumps**, 55 W each, pull enough on
start-up to dip the switching supply and make the dash boards flicker; the
capacitor rides out the dip. With the system off the contactor opens and the
capacitor's +12 V terminal floats, so it cannot keep anything alive.

The 24 V for the glycol pumps comes from an **MGGi 12→24 V boost converter**,
15 A, 360 W, non-adjustable 24 V out, in a potted die-cast aluminium case — the
finned module bolted on top of the supply box. Its output lands on distribution
strip 3 on the panel. The Cat5-coloured twisted pairs that pass below the box
are not part of it — they are the serial lines to the dash boards and the
switch pod ladder wires, routed past on their way to the panel.

From there 12 V is bussed across the back panel on more 6-way barrier strips
(600 V / 25 A rated) and fanned out with crimped ring and spade terminals.

Loads on the 12 V rail:

| Load | Notes |
| --- | --- |
| Dash boards | every ideegeniali board takes +12 V and GND on screw terminals; switched by the dash power relays |
| Fermenter heaters | SS Brewtech FTSs 12 V heating pads, one per fermenter, each behind its own 7.5 A fuse in the D-1384 and switched by relays 1–3 of the 6-way module |
| Glycol pumps | three Penguin Chillers XL pumps, 24 V, 55 W, 6 GPM, on 24 V from the MGGi 12→24 V boost converter, switched by the right three relays of the 6-way module |
| Raspberry Pis | through **two SSLHONG DC/DC buck converters** on the panel, 8–35 V in, 5 V 3 A out on USB-C, one per Pi, on the switched rail |
| Relay modules | the coil supply for the opto-isolated relay boards |
| PANP button lamps | 12 V, switched by the bottom three channels of the 8-way relay module |
| Switch pod lamps | 12 V, switched by channel 1 of the 4-channel module — lit in Pursuit only |

So the Pis *are* on the 12 V rail, via the two buck converters; the USB
adapters in the power strip in the 2023 photos were something else or since
removed. The Arduinos are powered over USB from their Pi.

### The Power button

`POWER` on the dash is the only PANP button that is not software, and it does
not switch any power itself. It is the trigger for a **HiLetgo 12 V bistable
self-locking relay module** at the bottom right of the control panel — press to
latch, press again to release — whose output drives the coils of the two 30 A
D-1012 contactors in the supply box. The lower contactor feeds the D-1384 fuse
block and so the whole switched rail, and everything downstream of it, the Pis
included, lives or dies with it; the upper one connects the buffer capacitor
across the 24 V converter's input at the same time.

```
  12 V rail ──▶ latching module COM ──▶ NC output ──▶ "master relay" cable ──▶ 2× D-1012 coils ──▶ switched 12 V
                       ▲                                     └──▶ POWER button lamp
                       │ trigger
  POWER button ──▶ rpints interlock (NC) ──▶ brewpi interlock (NC) ──┘
                   opens while rpints up     opens while brewpi up
```

**The 4-way terminal block** at the very bottom right is the junction:

| Terminal | Carries |
| --- | --- |
| 1 | +12 V in, from the supply box — the cable labelled **"master power"** |
| 2 | 0 V in, same cable |
| 3 | 0 V out |
| 4 | the latching module's **NC** output — the cable labelled **"master relay"**, to the two D-1012 coils and to the `POWER` button's lamp |

The master power pair feeds the latching module's own supply and also its `COM`
contact. **The output is taken from `NC`**, so with the module unlatched — its
state whenever the supply first comes up — the contactors are energised and the
system is on. Pressing `POWER` latches the module, opens `NC`, drops the
contactors and takes everything down; pressing it again releases the latch and
brings it all back. Unplugging the supply from the mains is the only way to
remove power from the latching module itself.

Between the button and the latching module's trigger input sit **two 5 V
single-channel relay modules, stacked one on the other, wired in series through
their `COM` / `NC` contacts** — one per Pi. Each is powered from its Pi's 5 V
and ground on the GPIO breakout HAT, and its `IN` is driven by:

- **`IO23` on rpints**, via `power-relay-rpints.service` (`raspi-gpio set 23 op pn dh`);
- **`IO5` on brewpi**, via `power-relay-brewpi.service` (`raspi-gpio set 5 op pn dh`).

Both are `oneshot` units that run early in boot, before `panp.py` starts, and
`panp.py` never touches these two pins. A high input energises the relay and
*opens* its NC contact, taking the `POWER` button out of the circuit. At halt,
`power-off-*.sh` in `/lib/systemd/system-shutdown/` drives the pin low as the
last act; the relay releases, the contact closes, and the button works again.

So the sequence, end to end:

1. Mains is applied to the supply box.
2. The latching module comes up unlatched, `NC` closed, and the two D-1012
   contactors close. 12 V reaches strip 1 and the two Pi buck converters.
3. Both Pis boot, and each powers its 5 V interlock relay module.
4. `power-relay-*.service` drives `IO23` on rpints and `IO5` on brewpi high.
   Either one alone breaks the series path from the `POWER` button to the
   latching module's trigger, so the button does nothing.
5. To make the button live again, `sudo halt` **both** Pis. Each shutdown
   script drops its pin, releasing its interlock.
6. Pressing `POWER` now latches the module, `NC` opens, the contactors drop,
   and the Pis and everything else lose 12 V.
7. The latching module is still powered from the master power pair, so a
   second press unlatches it and the system powers back up.
8. Unplugging the supply from the mains is what finally powers the latching
   module down.

That is the point of the interlocks: the boards write to EEPROM and the Pis
have SD cards, and neither likes having the power yanked. It is also why the
unit files are called *"Open … Power Relay"* — they open a contact, not a
circuit.

**After a mains outage the system comes back on its own**, because the output
is taken from `NC`. It used to be wired through `NO`, so the button had to be
pressed to power up, and a day without BrewPi control after an overnight outage
in July 2023 cost a batch of beer. Do not "tidy" this back to `NO`.

### The dash power relays

`rpints` owns three more relays that `panp.py` switches with the PANP modes.
They are **active low**: the pin is driven `0` to energise the relay and power
the load.

| GPIO | Header pin | `panp.py` name | Powered in |
| --- | --- | --- | --- |
| 10 | 19 | `lower_dash_power` | Norm, Pursuit |
| 18 | 12 | `upper_dash_power` | Norm, Pursuit |
| 17 | 11 | `sp_power` | Pursuit only |

Upper and lower dash are the two halves of the panel: the gauge cluster above
the bench and the strip of dummy3 boards and PANP buttons in the drawer front
below it. In Auto both are dark and only the message centre, which is on its
own relay driven from `brewpi`, stays lit. The third relay is the switch pods:
their lamps are bright enough to be a distraction, so they are only powered in
Pursuit, when the bench light is on and the dash is at full brightness anyway.

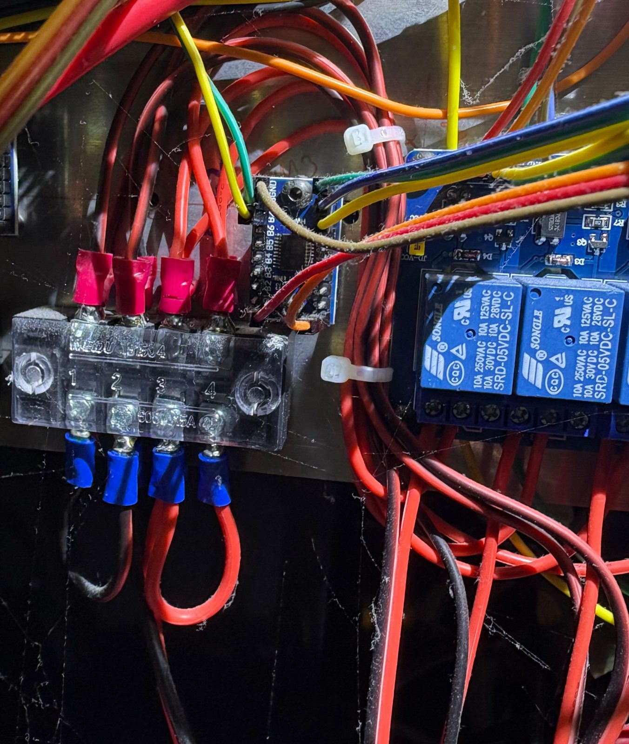
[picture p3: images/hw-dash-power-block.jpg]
The DASH POWER 4-way block and the 4-channel dash power module


Physically all of this is one **SunFounder 4-channel relay module** under the
`rpints` Pi. Like the 8-way module it is **shared between the Pis**: three
inputs come from rpints and the fourth from brewpi. Coil supply is 5 V and
ground from the rpints HAT, and the jumper on the module ties the relay supply
to that 5 V. The module is low-level trigger — a `0` on the input closes the
contact — which is why the code drives these pins low to power a board and high
to cut it.

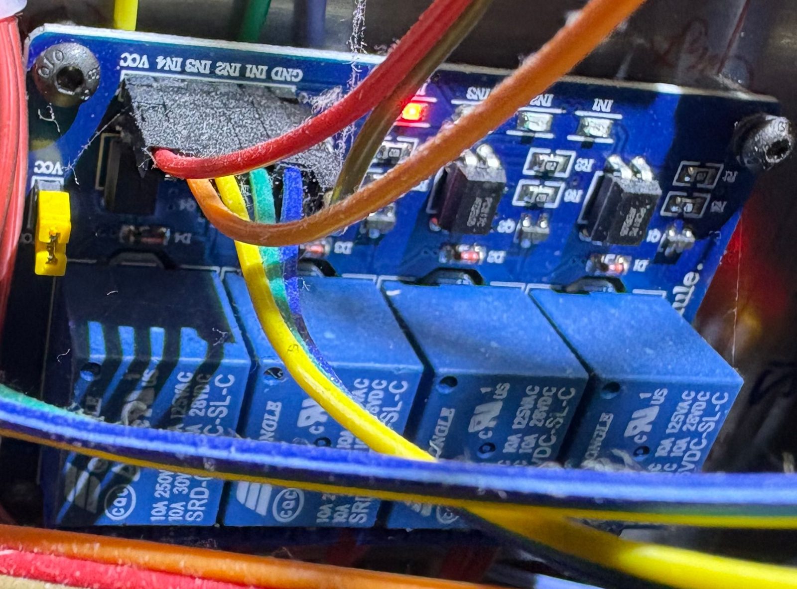
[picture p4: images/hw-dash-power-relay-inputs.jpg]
The 4-channel module's input side


| Ch | Input | Driven by | `panp.py` name | Contact feeds cable | Which powers | On in |
| --- | --- | --- | --- | --- | --- | --- |
| 1 | `IN1`, blue | rpints `IO17` | `sp_power` | `SPEED` | +12 V / 0 V to **both switch pods** | Pursuit only |
| 2 | `IN2`, green | rpints `IO18` | `upper_dash_power` | `TACHO` | **speedo, tacho and dummy6** — the whole upper panel | Norm, Pursuit |
| 3 | `IN3`, yellow | rpints `MOSI`, which is GPIO 10 | `lower_dash_power` | `DUMMY3` | **both dummy3 boards**, via a run inside the bench | Norm, Pursuit |
| 4 | `IN4`, orange | **brewpi** `IO16` | `msgctr_power` | `COMM` | **the message centre** | always, while brewpi is up |

**The cable labels lie**, and deliberately so: `SPEED` and `TACHO` are left
from when the pods were powered all the time and the speedo had its own relay.
Read the table, not the tag.

The 12 V comes in on a **4-way barrier block** to the left of the module, on the
cable labelled `DASH POWER` from the D-1384 fuse block: terminal 3 is +12 V and
2 is 0 V, with 3 jumpered to 4 and 2 jumpered to 1. +12 V goes from there to
each relay's `COM`; the 0 V conductor of each of the four dash cables lands on
the 0 V side. Each relay's `NO` is the +12 V conductor of its cable.

## The two Raspberry Pis

Both are **Raspberry Pi 4 Model B** (rpints rev 1.1, brewpi rev 1.5), running
Raspberry Pi OS, reachable as `rpints.local` at `10.0.1.31` and `brewpi.local`
at `10.0.1.32`. They are
configured almost identically in `/boot/firmware/config.txt`:

```
dtoverlay=disable-bt        # frees the PL011 UART for /dev/ttyAMA0
enable_uart=1
dtoverlay=uart4             # second UART on GPIO 8/9 → /dev/ttyAMA1
dtoverlay=w1-gpio,gpiopin=4
```

with `rpints` adding a second one-wire bus, `dtoverlay=w1-gpio,gpiopin=26`,
because it has nine probes to read and they are in two different keezers.

### Serial to the dash

Each Pi has two UART transmit lines going to the dash, one per bus, and each
bus is strapped to the `COM` terminal of one or more boards. The boards are
polled at 57600 baud and never answer — `panp.py` only writes — so only TX and
ground are connected. The tacho and speedo *do* have a TX terminal, but it is
5 V and would damage a Pi input, and nothing listens to it.

| Pi | Device | UART | TX on | Boards on the bus |
| --- | --- | --- | --- | --- |
| rpints | `/dev/ttyAMA0` | UART0 | GPIO 14, pin 8 | `G` dummy6, `E` red dummy3 |
| rpints | `/dev/ttyAMA1` | UART4 | GPIO 8, pin 24 | `A` tacho |
| brewpi | `/dev/ttyAMA0` | UART0 | GPIO 14, pin 8 | `C` message centre |
| brewpi | `/dev/ttyAMA1` | UART4 | GPIO 8, pin 24 | `B` speedo, `F` red/green dummy3 |

The serial runs to the dash are twisted pairs pulled from old Cat5, one solid
core for `TX` and its striped mate for ground. The Pi's UARTs are 3.3 V. Between
them and the boards is a **TXS0108E 8-channel bidirectional level shifter**, one
per Pi, with the A side on the Pi's 3.3 V and the B side on 5 V, both taken
from the GPIO HAT along with ground, and its `OE` pin driven from **GPIO 25**
(header pin 22).

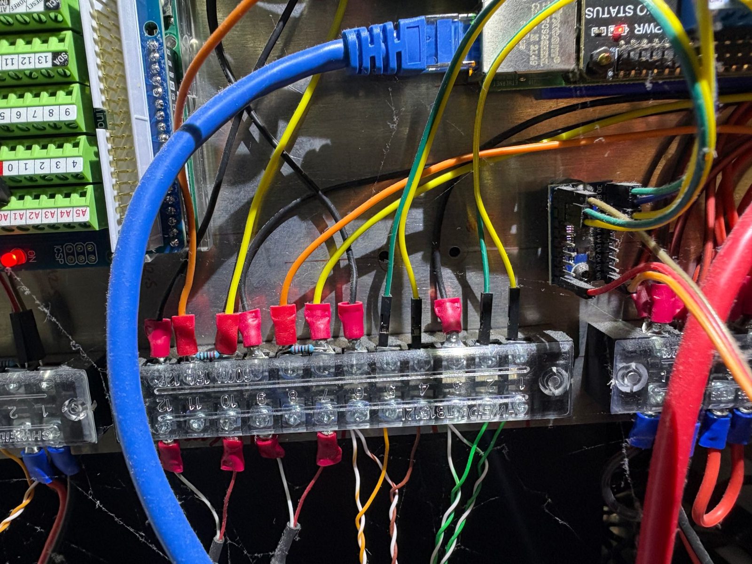
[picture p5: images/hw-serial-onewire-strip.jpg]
The 12-way strip carrying the four serial buses and two one-wire buses, with a level shifter at the right


All four serial lines land on the right-hand half of the **12-way barrier strip
to the left of the `DASH POWER` block**, terminal 1 at the right. rpints uses
the right-hand shifter and terminals 1–3, brewpi the left-hand shifter and
terminals 4–6:

| Strip | Pi | Pi pin | Shifter | Field side, traced |
| --- | --- | --- | --- | --- |
| 1 | rpints | `TXD`, GPIO 14, `ttyAMA0` | one of `A6`/`B6`, `A7`/`B7` | solid green to the **red dummy3** `COM`, daisy-chained on to **dummy6** — the three lager temperatures and the six fill levels |
| 2 | rpints | `CE0`, GPIO 8, `ttyAMA1` | the other | solid green to the **tacho** `COM` — the six keezer probes and the selected reading |
| 3 | rpints | `GND` | | both green/white, ground for the two buses |
| 4 | brewpi | `TXD`, GPIO 14, `ttyAMA0` | yellow → `A7`/`B7` → yellow | solid brown to the **message centre** `COM` |
| 5 | brewpi | `CE0`, GPIO 8, `ttyAMA1` | blue → `A6`/`B6` → green | solid orange to the **speedo** `COM` and the **red/green dummy3** — the HLT and multifunction readings, and the fermenter temperatures |
| 6 | brewpi | `GND` | | brown/white and orange/white, ground for the two buses |
| | both | `IO25` | `OE` | |

The field side was traced. On the rpints rows the Pi side is taken from the
code, which the Pi's device tree confirms: `ttyAMA0` is UART0 on GPIO 14 and
`ttyAMA1` is UART4 on GPIO 8, and `panp.py` opens `ttyAMA0` for the dummies and
`ttyAMA1` for the tacho. The two rpints jumper colours are not reliably
recorded, so which of its shifter channels is which is left open **(confirm)**.
Only `TX` and ground are wired; the boards' `RX` is their `COM`, and their `TX`
terminals are left unconnected. `panp.py` raises the shifter's `OE` first thing
at startup and drops it in the SIGTERM handler, so the boards see nothing on the
bus while a Pi is booting or halting.

The left-hand half of the same strip is the two panel-side one-wire buses, one
per Pi, laid out as mirror images. Each is three terminals: data, a 3.3 V
supply terminal with a **2.2 kΩ 1 % pull-up** soldered across to the data
terminal, and ground. Only **two** field conductors arrive per bus, data and
ground, so the probes run in **parasite-power mode**: their `VDD` is tied to
ground at the probe end and they draw what they need through the data line and
the pull-up **(confirm)**.

| Strip | Field side | Panel side | Role |
| --- | --- | --- | --- |
| 7 | red | yellow, to rpints `IO26`; 2.2 kΩ across to 8 | one-wire data, the **three lager probes** |
| 8 | none | orange, to **`3V3` on the RaspberryPints Uno** | 3.3 V for the pull-up |
| 9 | white | black, to rpints `GND` | ground |
| 10 | red | yellow, to brewpi `IO4`; 2.2 kΩ across to 11 | one-wire data, the **mash and HLT probes** |
| 11 | none | orange, to brewpi `3V3` | 3.3 V for the pull-up |
| 12 | white | black, to brewpi `GND` | ground |

Both buses are pulled up to 3.3 V, which is what keeps the data lines inside
the Pis' GPIO range. Both of rpints's buses, this one and the keezer bus on the
3-way block, take their 3.3 V from the RaspberryPints Uno's `3V3` pin rather
than from the Pi's own rail, to keep the pull-up and probe load off the Pi's
3.3 V regulator; brewpi's bus uses the Pi's `3V3`. The resistor value was read
from the colour bands, red-red-black-brown-brown; a meter across 10 and 11
would confirm it.

The keezer probes are the exception: their bus does not come to this strip at
all. It arrives on the serving keezer's 8-way strip, is pulled up on the 3-way
block, and lands on rpints `IO4`.

### One-wire probes

All temperature probes on the Pi side are **DS18B20s** — the common stainless
steel waterproof probe on a 1 m three-core lead, red VCC, yellow data, black
ground (see [Parts](#parts)) — read through the kernel's `w1-gpio` driver at
`/sys/bus/w1/devices/28-*/w1_slave`. `panp.py` lists them by serial number, so
a replaced probe means editing the list.

| Pi | Bus | GPIO | Probes | Serials |
| --- | --- | --- | --- | --- |
| brewpi | 1 | 4 (pin 7) | mash tun, HLT | `28-012052b65be5`, `28-0120529d8f20` |
| rpints | 1 | 26 (pin 37) | 3 lager kegs | `28-3c01b556f6d0`, `28-3cdd04574813`, `28-3ce80457395a` |
| rpints | 2 | 4 (pin 7) | 6 serving keezer | `28-012052b92541`, `28-012058f936f3`, `28-012052ba8dab`, `28-012058fbceb5`, `28-012058fc2851`, `28-012052b426ca` |

On rpints the **lager bus is GPIO 26 and the keezer bus GPIO 4** — the reverse
of the order the overlays appear in `config.txt`. The kernel probed
`onewire@1a`, GPIO 26, first and numbered it `w1_bus_master1`, which is the
master that holds the lager probes; `dmesg` shows it, and the wiring agrees.
The keezer probes are the ones with `28-012…` serials, the lager probes
`28-3c…` — a different batch, which is a handy way to tell them apart.

### GPIO, `rpints`

| GPIO | Pin | Direction | Used for |
| --- | --- | --- | --- |
| 25 | 22 | out | serial level-shifter enable |
| 7 | 26 | out | `auto_mode_comm` → brewpi GPIO 7 |
| 22 | 15 | out | `normal_mode_comm` → brewpi GPIO 22 |
| 10 | 19 | out, active low | lower dash power relay |
| 18 | 12 | out, active low | upper dash power relay |
| 17 | 11 | out, active low | Pursuit relay (`sp_power`) |
| 19 | 35 | out | `AUTO` lamp |
| 20 | 38 | out | `NORM` lamp |
| 12 | 32 | out | `PURSUIT` lamp |
| 5 | 29 | in, pull-up | `AUTO` button |
| 6 | 31 | in, pull-up | `NORM` button |
| 16 | 36 | in, pull-up | `PURSUIT` button |
| 23 | 16 | out | Power disconnect relay (held high while up) |
| 4 | 7 | 1-wire | keezer probes, from the 3-way block |
| 26 | 37 | 1-wire | lager probes, from the 12-way strip |
| 14 | 8 | UART0 TX | dummy6 and red dummy3 |
| 8 | 24 | UART4 TX | tacho |

The PANP buttons are momentary contacts to ground; `panp.py` enables the
internal pull-ups and triggers on the falling edge with 50 ms of debounce, then
re-reads the pin 50 ms later before acting. The lamps are driven high to light:
each lamp GPIO goes to one of the bottom three channels of the 8-way relay
module, which switches 12 V from distribution strip 1 to the 12 V illuminated
pushbutton.

### GPIO, `brewpi`

| GPIO | Pin | Direction | Used for |
| --- | --- | --- | --- |
| 25 | 22 | out | serial level-shifter enable |
| 7 | 26 | in, pull-down | Auto mode, from rpints |
| 22 | 15 | in, pull-down | Norm mode, from rpints |
| 16 | 36 | out | message centre power relay (`msgctr_power`) |
| 2 | 3 | out, active high | flow meter 1 relay |
| 3 | 5 | out, active high | flow meter 2 relay |
| 27 | 13 | out, active high | flow meter 3 relay |
| 21 | 40 | out, active high | flow meter 4 relay |
| 13 | 33 | out, active high | flow meter 5 relay |
| 5 | 29 | out | Power disconnect relay (held high while up) |
| 4 | 7 | 1-wire | mash and HLT probes |
| 14 | 8 | UART0 TX | message centre |
| 8 | 24 | UART4 TX | speedo and red/green dummy3 |

GPIO 2 and 3 are the I²C pins; brewpi does not enable I²C so they are plain
outputs here. Note that GPIO 5 and 16 mean different things on the two Pis —
buttons on rpints, relays on brewpi — which is one reason to read `panp.py`
twice, once as each host.

`msgctr_power` is initialised to 0 and only ever written 0 again at shutdown.
It drives `IN4` of the SunFounder 4-channel module under the rpints Pi, which
is low-level trigger, so the message centre is powered the whole time brewpi's
`panp.py` is running and only drops when the Pi releases the pin at power-off.
That is what keeps the message centre lit in Auto while the rest of the dash is
dark.

### The link between the Pis

Two plain 3.3 V GPIO lines, same BCM numbers at both ends, ground common through
the shared supply. `rpints` drives them; `brewpi` reads them with pull-downs and
edge-detect callbacks.

| Mode | GPIO 7 (`auto_mode_comm`) | GPIO 22 (`normal_mode_comm`) |
| --- | --- | --- |
| Auto | 1 | 0 |
| Norm | 0 | 1 |
| Pursuit | 0 | 0 |

`brewpi` uses GPIO 7 to decide whether anyone is looking at the dash and GPIO 22
to pick dim or bright. `rpints` reads GPIO 22 back itself to set its own boards'
brightness, which is why `BrightnessHandler` takes a channel argument.

## The six Arduinos

All six are **Arduino Uno R3** boards (USB `2341:0043`), plugged into their Pi
over USB and given stable names by udev rules matching the board's serial
number, so the ports do not shuffle on reboot. Every one of them sits under an
HCDC screw-terminal breakout shield (see [Parts](#parts)), so all field wiring
lands on screw terminals rather than header pins.

| Pi | Hub port | udev name | USB serial | On the panel | Job | Firmware |
| --- | --- | --- | --- | --- | --- | --- |
| brewpi | 1.3 | `/dev/unitank-1` | `24230303537351E08050` | middle row, **left-most** of the three; relays 1 and 4 | fermentation controller | BrewPi Remix |
| brewpi | 1.1 | `/dev/unitank-2` | `24238313635351410240` | middle row, **middle** of the three; relays 2 and 5 | fermentation controller | BrewPi Remix |
| brewpi | 1.2 | `/dev/chronical` | `2423632373035110C052` | middle row, **right-most** of the three; relays 3 and 6 | fermentation controller | BrewPi Remix |
| brewpi | 1.4 | `/dev/switchpod` | `24238313535351F0D112` | bottom left, the **right-hand** of the two; orange twisted pair to the **left** pod | left switch pod ADC | [`kitt/switchpod`](kitt/switchpod/) |
| rpints | 1.3 | `/dev/rpints` | `85935333337351A01151` | middle row, right of centre, rainbow ribbon on pins 6–10 | flow meter pulse counter | RaspberryPints |
| rpints | 1.4 | `/dev/switchpod` | `24238313635351915202` | bottom left, the **left-most**; blue twisted pair to the **right** pod | right switch pod ADC | [`kitt/switchpod`](kitt/switchpod/) |

The two switch pod Unos are crossed: the left-most board on the panel serves
the right-hand pod, and the one beside it serves the left-hand pod. Follow the
twisted pair, blue to the right pod and orange to the left, not the position.

The hub port is the Pi 4's internal hub port as `/dev/serial/by-path` reports
it, which follows the physical USB socket rather than the board. Ports 1.3 and
1.4 share one stacked connector, 1.1 and 1.2 the other. The udev rules match on
the USB serial, so a replaced Uno keeps its socket but not its name until the
rule is edited.

The rules live in `/etc/udev/rules.d/` on each Pi and are not in this
repository. `panp.path` waits for `/dev/switchpod` to exist before starting
`panp.py`, which is what the naming is for.

## The dash

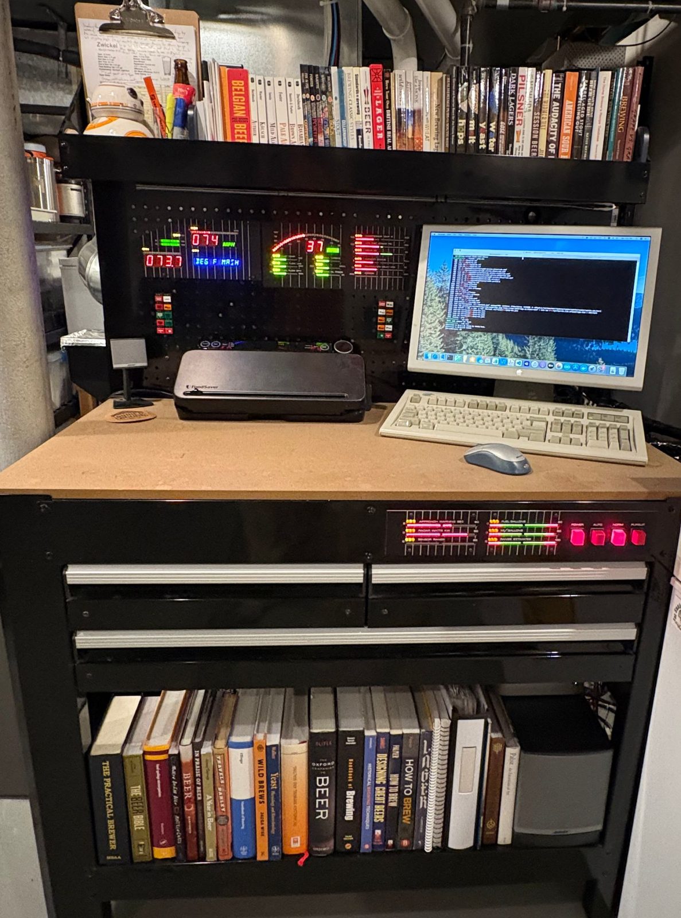
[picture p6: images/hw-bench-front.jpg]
The bench from the front


The whole dash is built into a **Kobalt 45 in × 36 in three-drawer hardwood
workbench** with a pegboard back. The gauge cluster and the two switch pods sit
in cut-outs Dremelled through the pegboard, with the face plates screwed to its
front; the drawer front below the top carries the strip of dummy3 boards and
the PANP buttons. Everything else — the supply box, the buffer capacitor, the
control panel, the backs of the display boards — hangs on the rear of the
pegboard, which is why the earlier photographs of the capacitor show the back
of dummy6 and the right switch pod beside it. Every display on the dash is an
[ideegeniali](https://www.ideegeniali.it/) board — Paolo Sancono's replicas of
KITT's season 2 dash electronics:

| Board | Address | Where |
| --- | --- | --- |
| tacho | `A` | upper, centre |
| speedo | `B` | upper, left |
| message centre 2.1 | `C` | upper, left — mounted on the back of the speedo |
| dummy3, all red | `E` | drawer front, left |
| dummy3, red/green | `F` | drawer front, centre |
| dummy6 | `G` | upper, right |
| PANP keys | — | drawer front, right; four illuminated pushbuttons |
| two switch pods | — | either side of the upper panel, below the gauges |

What the boards have in common: 12 V in on screw terminals, a `COM` screw
terminal for the serial bus, and an ATmega328 in a socket with a 6-pin ICSP
header beside it. The socket matters because the ATmega's internal EEPROM is the
only thing on the boards that wears out (see [CLAUDE.md](CLAUDE.md)), so a worn
board is fixed by pressing in a new chip. The protocol, and which host drives
which board, are in [kitt/README.md](kitt/README.md); everything about the
boards' internals is in the private repo and stays there.

The tacho and speedo also carry the inputs they would have in a car — speed
sensor, fuel sender, bar inputs — on their terminal strips. None of those are
used here; the 2023 firmware extensions exist precisely so the host can set
those displays instead.

One exception is wired deliberately. The speedo's four optocoupled warning
inputs, `BAR1`–`BAR4`, each light one of the green light bars behind the
`GUIDANCE` and `SYST. RDY` legends; Paolo meant them for turn signals and
dash warnings. On the speedo's own 12-way terminal block the four are
daisy-chained with white jumpers and fed +12 V by a red wire from the supply
terminal, so the firmware sees all four asserted and the legends are always
lit. They are the only lights on the dash the Pi does not control: to use them
as warning lamps, either move the strap to a Pi GPIO through the existing
optocouplers, or add a host register in the speedo firmware. The `KMH`/`MPH`
header beside the ICSP pins is Paolo's units jumper for the car speed input
and does nothing here.

The message centre and the speedo are the two boards that get hot: the speedo
has the most LEDs and the message centre is bolted to its back, all behind a
solid panel with no airflow. The speedo's habit of running dim, which heat
was suspected of, turned out to be EEPROM wear in its ATmega caused by the
firmware, fixed in September 2026 — see the EEPROM section of `CLAUDE.md`.
Nothing points at the heat doing harm, but the boards do run warm.

### PANP switches

The four `POWER` / `AUTO` / `NORM` / `PURSUIT` keys are Honeywell MICRO SWITCH
illuminated pushbuttons, marked `4A13BAA31`: a momentary contact on `C` / `NO` /
`NC` spade terminals rated 5 A at 250 VAC, and a separate lamp on terminals `5`
and `2`. The holder is rated 28 V max and the lamps fitted are **12 V**. Each
button uses **four wires** — `C`, `NO`, lamp `5`, lamp `2` — so the four buttons
fill two uxcell 8-core cables exactly, nothing shared on the way to the panel.
`PURSUIT` and `POWER` are mounted upside down relative to `AUTO` and `NORM`; the
buttons are symmetric from the front, so nothing shows. The yellow/green core of
each cable is used for `POWER`.

**Relamping.** Per Honeywell's Series 4 datasheet (Mouser `c30099-260707`),
the button pulls straight out of the housing from the front and the lamp
comes out with it, held in the button; the new lamp goes into the button and
the button pushes back in, no tools. The lamp is a **T-3¼ wedge base**: the
`31` in the part number means they shipped with a 28 V #656 or #152, and the
12 V lamps fitted are the #161 equivalent. **But `4A13B` is the housing "with
provision for locked button"**: if the locking mounting clip is fitted, it
holds the button in and the datasheet says such units cannot be relamped from
the front — the mounting clip must be slid off from behind the panel first.
If a button will not pull out with a firm straight pull, that is why; do not
force it.

**Fault log.** 2026-09-21: the `NORM` lamp went dark intermittently while
GPIO 20 was high, relay 7's indicator lit and +12 V present at its `NO`
terminal; pressing keys or moving the desk brought it back and jiggling the
cable did nothing. So the fault is at the key — a wedge lamp loose in its
socket, or the lamp spades — not the Pi, the relay or the wiring.

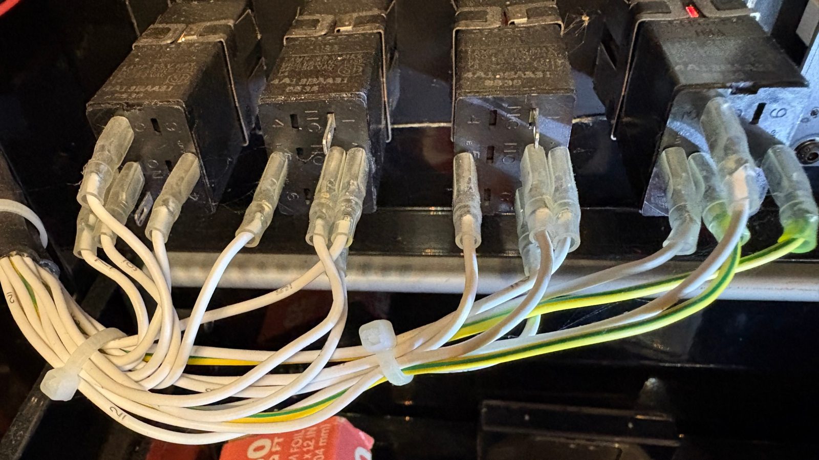
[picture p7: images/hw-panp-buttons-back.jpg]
The backs of the four PANP switches: Pursuit, Norm, Auto, Power


The cables land on the **lower two 8-way barrier strips** at the right-hand edge
of the control panel, numbered 1 at the bottom:

**Lower strip** (tagged `PURS`, `AUTO`, `NORM` on the cable tie):

| Pos | Wire | Goes to |
| --- | --- | --- |
| 1 | `POWER` `NO` (yellow/green) | the interlock chain, then the latching module's trigger — see [The Power button](#the-power-button) |
| 2 | `POWER` `C` | the other side of that chain |
| 3 | `POWER` lamp +12 V | the "master relay" line, so the lamp is lit whenever the contactors are |
| 4 | `POWER` lamp 0 V | 0 V |
| 5 | `AUTO` `NO` | rpints `IO5`, purple |
| 6 | `NORM` `NO` | rpints `IO6`, blue |
| 7 | `PURSUIT` `NO` | rpints `IO16`, green |
| 8 | `C` common | jumpered to middle strip 1 |

Note the colours: on the button side `AUTO` is purple, `NORM` blue and `PURSUIT`
green, but on the lamp relay inputs below the same three colours run the other
way, purple for `PURSUIT` and green for `AUTO`. Trace, don't trust the colour.

**Middle strip**:

| Pos | Wire | Goes to |
| --- | --- | --- |
| 1 | `C` common | jumpered from lower 8 |
| 2 | `C` common | jumpered from 1, to rpints `GND` |
| 3 | `AUTO` lamp +12 V | 8-way relay module, relay 8 `NO` (red) |
| 4 | `NORM` lamp +12 V | relay 7 `NO` (brown) |
| 5 | `PURSUIT` lamp +12 V | relay 6 `NO` (black) |
| 6 | lamp 0 V | jumpered from 7 |
| 7 | lamp 0 V | jumpered from 8 |
| 8 | lamp 0 V | in from distribution strip 1, terminal 3 |

The three software buttons' `C` contacts are commoned to the Pi's ground
through lower 8 → middle 1 → middle 2, so a press pulls the `IO` pin down
against its internal pull-up, which is the falling edge `panp.py` watches for.

The lamps are 12 V, so the Pi drives them through the **bottom three channels
of the 8-way relay module**. +12 V from distribution strip 1 terminal 6 goes to
relay 6 `COM` and is jumpered on to relays 7 and 8; each `NO` returns to the
middle strip as that lamp's +12 V line. The inputs are high-level trigger, so a
high on the pin lights the lamp:

| Relay | Input from | Lamp |
| --- | --- | --- |
| 6 | rpints `IO12`, purple | `PURSUIT` |
| 7 | rpints `IO20`, blue | `NORM` |
| 8 | rpints `IO19`, green | `AUTO` |

### Switch pods

Each pod is ten pushbuttons on a **resistive ladder** — one signal wire whose
voltage depends on which button is down. It goes to `A0` of its own Uno with a
3k3 pull-up to 5 V; the Uno bins the ADC reading into a position 0–9 and sends
it up USB as one digit per line. Wiring, thresholds and the calibration method
are in [kitt/switchpod/README.md](kitt/switchpod/README.md).

The **right** pod's Uno is on `rpints` and chooses what the tacho digits show;
the **left** pod's is on `brewpi` and chooses the speedo's lower display or
toggles a flow meter. Both Unos are on the control panel, bottom left. Each pod
has two connections to the panel: the signal-and-ground pair to its Uno, and a
+12 V / 0 V pair on the cable labelled `SPEED` from channel 1 of the 4-channel
dash power module. The pods' LEDs are internal and run from that 12 V: **yellow
and green are on whenever the pod is powered, red lights while a button is
pressed**. Because channel 1 is `sp_power`, low only in Pursuit, the pods are
dark in Auto and Norm — the buttons still work, only the lamps are off.

## Hot side

A three-vessel electric HERMS to The Electric Brewery's design — HLT, mash tun,
boil kettle, two pumps, HERMS coil in the HLT — with its own control panel doing
all the heating control. That panel is documented by its designer and is
deliberately not described here.

The only connection to the rest of this system is **two DS18B20 probes**, one in
the mash tun and one in the HLT, on `brewpi`'s one-wire bus. They are read every
second by `panp.py`, nothing else, and they drive:

- the `MPH` digits and the bargraph above them — HLT temperature, always;
- the lower multifunction display when `SILENT MODE` or `TEAR GAS` is selected —
  mash or HLT respectively.

Both probes sit in **stainless steel thermowells** fitted to the mash tun and
the HLT, so the DS18B20s themselves stay dry and can be pulled without draining
a vessel.

## Cold side

### Fermenters

Three SS Brewtech conicals: two **Unitanks** and one **Chronical**. Each has its
own temperature control loop with a **heater** and a **glycol cooling coil**
with its own pump, and each is run by its own **BrewPi Remix** controller: one
Uno on `brewpi` per fermenter, three instances of the Remix script in
`/home/brewpi/{unitank-1,unitank-2,chronical}/`, three web front-ends under
`/var/www/html/`.

The three controllers are configured identically, read live off the Arduinos:

| | Pin | BrewPi role |
| --- | --- | --- |
| DS18B20 in the fermenter | `A0` (one-wire) | chamber temperature |
| heat relay | `5` (Act 1) | chamber heater |
| cool relay | `6` (Act 2) | chamber cooler |
| free | `2` (Act 3), `10` (Act 4) | — |

The shield profile is Remix's "I²C" one, which puts one-wire on `A0` rather than
the legacy `A4`. There is a single probe per fermenter and it is registered as
the *chamber* sensor, so BrewPi runs in what is effectively fridge-constant
mode with the setpoint applied directly to the wort — the Unitank's thermowell
*is* the chamber. Probe addresses, for the record: `28BD2057047A3C27` on
unitank-1, `28EACCED582001EE` on unitank-2, `283213C85820014B` on the chronical.

The three probes do not go to the Unos directly. They land on a **10-way
barrier strip to the left of the unitank-1 Uno**, three terminals per
fermenter with the tenth spare, and short jumpers run from there to each Uno's
screw shield. Each group is data, supply and ground, with a **4.7 kΩ 1 %
pull-up** from data to supply soldered across the strip. Unlike the two Pi
buses these run at **5 V** from the Uno, so the standard DS18B20 pull-up value
is used rather than the 2.2 kΩ on the 3.3 V buses.

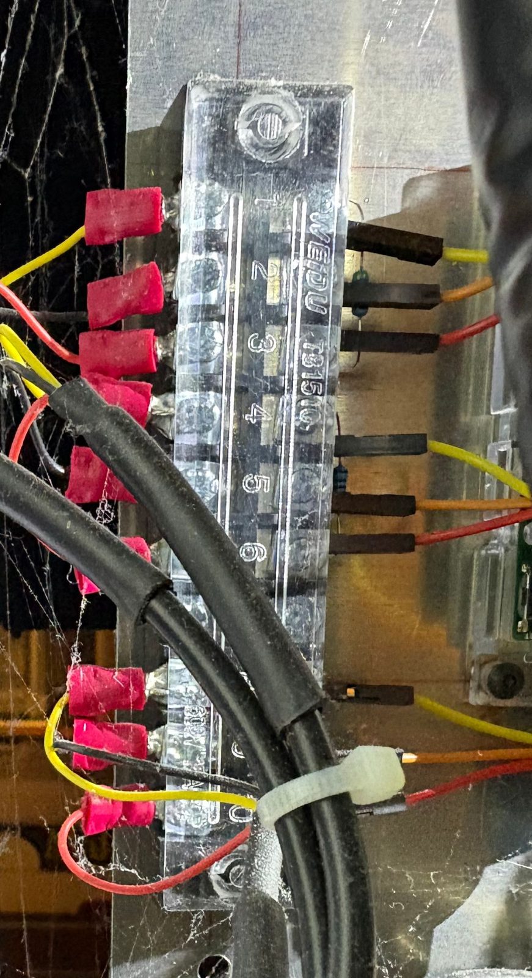
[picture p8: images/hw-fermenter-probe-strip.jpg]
The 10-way fermenter probe strip


| Pos | Field side | To the Uno | Role |
| --- | --- | --- | --- |
| 1–3 | yellow, red, black | `A0`, `5V`, `GND` | **unitank-1** probe: data with 4.7 kΩ to supply, supply, ground |
| 4–6 | yellow, red, black | `A0`, `5V`, `GND` | **unitank-2** probe, likewise |
| 7 | | | not connected |
| 8–10 | yellow, red, black | `A0`, `5V`, `GND` | **chronical** probe, likewise |

On the field side the probe leads keep their colours — red supply, yellow data,
black ground. The jumper colours on the Uno side do not follow them, so trace
rather than trust a colour there.

The heat and cool outputs go to the ANMBEST 6-channel relay module on the back
panel, heaters on relays 1–3 and glycol pumps on relays 4–6. The outputs are
configured "not inverted" in BrewPi, so a high on the pin closes the relay and
the module is jumpered for high-level trigger. The heat relay passes the
fermenter's own 7.5 A-fused 12 V feed from distribution strip 2 out to its
heating pad, by way of the `H1`–`H3` block on the back of the workbench; the
cool relay switches its 24 V glycol pump — a Penguin Chillers XL, 55 W — from
strip 3 onto strip 4.

The heaters are **SS Brewtech FTSs 12 V heating pads**. The chronical and
unitank-2 have the legacy **60 W pad with a barrel jack**; unitank-1 has the
newer **FTSs Touch pad with an XT30 connector**, SS Brewtech SKU `HTR180WXT`.
Both are the pad SS Brewtech sells for its own FTSs controller; here BrewPi
drives them directly through the relay instead.

| Fermenter | Uno on the panel | Heat relay | Cool relay |
| --- | --- | --- | --- |
| unitank-1 | left-most of the three | **1** | **4** |
| unitank-2 | middle | **2** | **5** |
| chronical | right-most | **3** | **6** |

So the three Unos sit in the same order as the fermenters' relays, left to
right, and the heat relay number is the fermenter number, the cool relay that
plus three. All three were confirmed from their BrewPi device pages and by
following the pin 5 and pin 6 jumpers to the relay module.

**Glycol.** Two identical **SS Brewtech 1/5 hp glycol chillers** — 1450 BTU/h,
4.75 gal reservoir, 120 VAC, each rated for up to three FTSs loops — stand in
for the cold side of the loops. The pumps sit *in* the reservoirs, each pushing
glycol out through its fermenter's coil and back:

| Chiller | Set to | Pumps in the reservoir |
| --- | --- | --- |
| 1 | 23 °F | unitank-1 and unitank-2 — Penguin Chillers XL, switched by BrewPi relays 4 and 5 |
| 2 | 26 °F | the chronical — Penguin Chillers XL on relay 6 — and a fourth, **always-on** pump feeding the glycol line of the long-draw draft trunk (see [Taps and flow meters](#taps-and-flow-meters)) |

The chillers hold their own reservoir temperature with their built-in
controllers; BrewPi only decides when each fermenter's pump runs. The fourth
pump is outside the system altogether: it runs from its own Penguin Chillers
mains adapter and keeps circulating whatever the dash and the Pis are doing.

**Specific gravity** comes from a **Tilt hydrometer** floating in each fermenter
— Red in unitank-1, Green in unitank-2, Blue in the chronical — read by a
**TiltBridge** (an ESP32 with Bluetooth and WiFi) that forwards the readings to
each BrewPi instance over the network. BrewPi Remix does not ask the Pi's own
Bluetooth for them; the Pis have Bluetooth disabled to free the UART.

`panp.py` gets fermenter data from each BrewPi instance over a Unix socket,
`KITTSOCKET`, that the Remix script opens alongside its normal `BEERSOCKET`.
That is a change on the `kitt` branch of
[duncan-brown/brewpi-script-rmx](https://github.com/duncan-brown/brewpi-script-rmx),
not on `main`; the three instances on the Pi run that branch. What it does, and
the state it is in, is in [kitt/README.md](kitt/README.md#the-brewpi-side).

### Lagering keezer

A chest freezer holding **three kegs**, held at lagering temperature by an
**A419** on its own — the Pis do not control it. One **DS18B20 per keg** on
`rpints`'s first one-wire bus feeds the three red/green bars at the top of
dummy6 and, on request from the right pod, the tacho digits.

### Serving keezer

A chest freezer holding **five kegs** — normally four 5-gallon kegs and a
2.5-gallon cask — also on its own **A419**. **Six DS18B20s** on `rpints`'s
second one-wire bus: one per keg and one for the keezer air. All six run on the
RaspberryPints Uno's 5 V and share one data line, which travels back to the
panel in the same 8-core cable as the flow meters, is pulled up to the Uno's
3.3 V on a small 3-way barrier block, and lands on GPIO 4.
They feed the six tacho bars, and the mean of the six is what the tacho digits
show by default.
The keezer's circulation fan is deliberately off so the six bars show the
stratification.

### Taps and flow meters

The five beer lines do not end at the keezer. They run to a bar elsewhere in a
**glycol-cooled long-draw trunk line**, built along the lines of the
[BYO DIY draft trunk line](https://byo.com/projects/diy-draft-trunk-lines-when-you-want-to-run-long-draft-lines/):
the five beer lines bundled with a glycol line and its return, insulated, with
the glycol circulated continuously by the always-on fourth pump in the 26 °F
chiller so the beer stays cold all the way to the taps.

Each of the five beer lines carries a **SwissFlow SF800** inline flow meter. The
SF800 is a turbine with a Hall sensor and an open-collector pulse output — about
5,600 pulses a litre — powered from 5–24 V, so it can hang off the 12 V rail or
the Arduino's 5 V.

The five meters come back from the keezer on one **uxcell 8-core 20 AWG cable**,
shared with the six keezer probes, to the upper 8-way barrier strip at the
right-hand edge of the control panel (its pinout is under
[The control panel](#the-control-panel)), and from there through the relays
below to the RaspberryPints Uno on `rpints`, which counts the pulses
with pin-change interrupts and reports pours up the USB link to `PintDispatch`.
The pin assignment is in the RaspberryPints database, not the sketch:

| Tap | Uno pin |
| --- | --- |
| 1 | `D6` |
| 2 | `D7` |
| 3 | `D8` |
| 4 | `D9` |
| 5 | `D10` |

RaspberryPints enables the internal pull-ups on those pins, so the SF800's
open-collector output needs no external resistor. Tap valves, RFID and fan
control are all turned off in its configuration; it is used purely for keg
volume tracking, and `panp.py` reads the remaining volumes straight out of its
MariaDB (`vwGetActiveTaps`) every tenth loop.

Separately, each flow meter can be switched on and off from the **left switch
pod** through one of five relays on `brewpi` — `LASER` through `H6`, one per
tap. The relays are five channels of the 8-way module on the control panel and
they **break the pulse line** between the barrier strip and the Uno's input
pin; the meter itself stays powered. They are active high and come up off, so
after a reboot no tap counts until it is switched on. The message centre says
`FLOW n on` when you do. The point is that pours are not counted while cleaning
lines or swapping kegs.

RaspberryPints' tap list is also shown on a screen in the brewery in a
**Chrome kiosk**. The kiosk machine is nothing special — any box with a browser
pointed at rpints's web server, **`http://10.0.1.31/`** — and it is not either
Pi; there is no browser process on `rpints`.

## The control panel

A sheet of aluminium behind the dash carries everything between the supply box
and the loads. Top to bottom, as it is laid out; every module here has been
walked terminal by terminal except where marked:

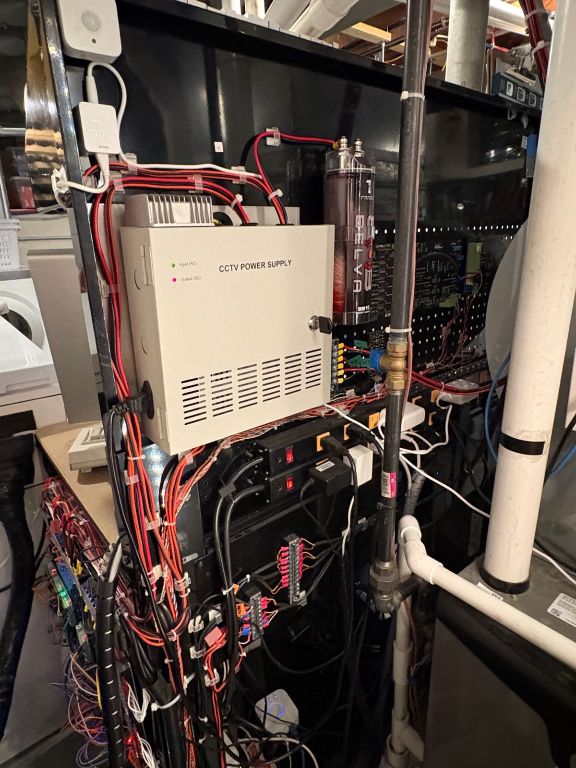
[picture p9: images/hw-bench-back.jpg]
The bench from the back: supply box, capacitor, dummy6 and the control panel below


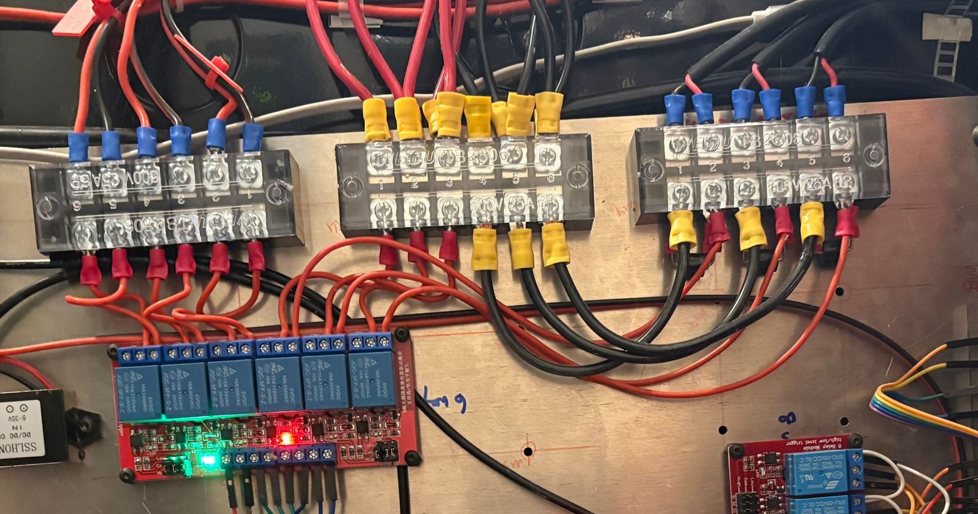
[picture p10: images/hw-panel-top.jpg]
The top of the control panel: distribution strips, Pi converters, the 6-channel relay module and the BrewPi Unos


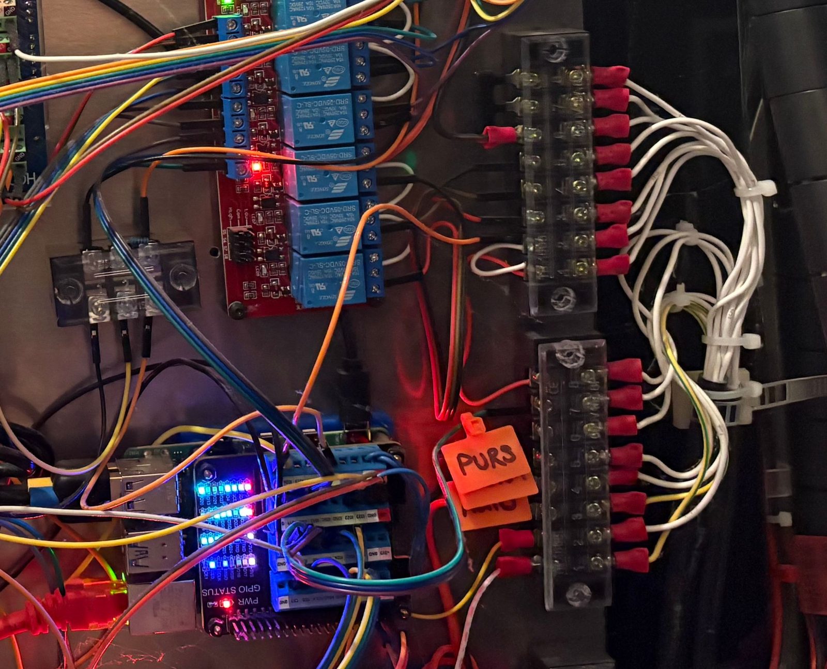
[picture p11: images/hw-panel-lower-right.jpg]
The lower right of the panel: the 8-way relay module, the PANP strips and the rpints Pi


**Distribution strips.** Four 6-way barrier strips (600 V / 25 A) across the
top, numbered left to right:

| Strip | Carries | Wiring |
| --- | --- | --- |
| 1 | **switched, fused 12 V in** — cable `P1` from the D-1384 fuse block | feed lands on terminal 3 (0 V) and 4 (+12 V); 1–2–3 jumpered as 0 V, 4–5–6 jumpered as +12 V. Terminals 1, 2 and 4, 5 are 0 V and +12 V to the two Pi buck converters; 3 and 6 are 0 V and +12 V for the `AUTO`, `NORM` and `PURSUIT` lamps, switched through the bottom three channels of the 8-way relay module |
| 2 | **fused 12 V for the fermenter heaters** | three separately fused +12 V feeds in from the D-1384's `V3`, `V4` and `V5`, each 7.5 A, one per heater; from here to `COM` on relays 1, 2 and 3 of the 6-way module |
| 3 | **24 V bus** | the MGGi 12→24 V converter's output lands on the centre two terminals; 1–2–3 jumpered as +24 V, 4–5–6 as 0 V. +24 V goes into the right three relays of the 6-way module |
| 4 | **24 V to the glycol pumps** | the switched +24 V from those relays, one pair per fermenter |

"Switched" on strip 1 means downstream of the `POWER` button and the two
disconnect relays, so the Pis themselves are on the switched rail — which is
exactly why the disconnects have to hold until both Pis have halted.

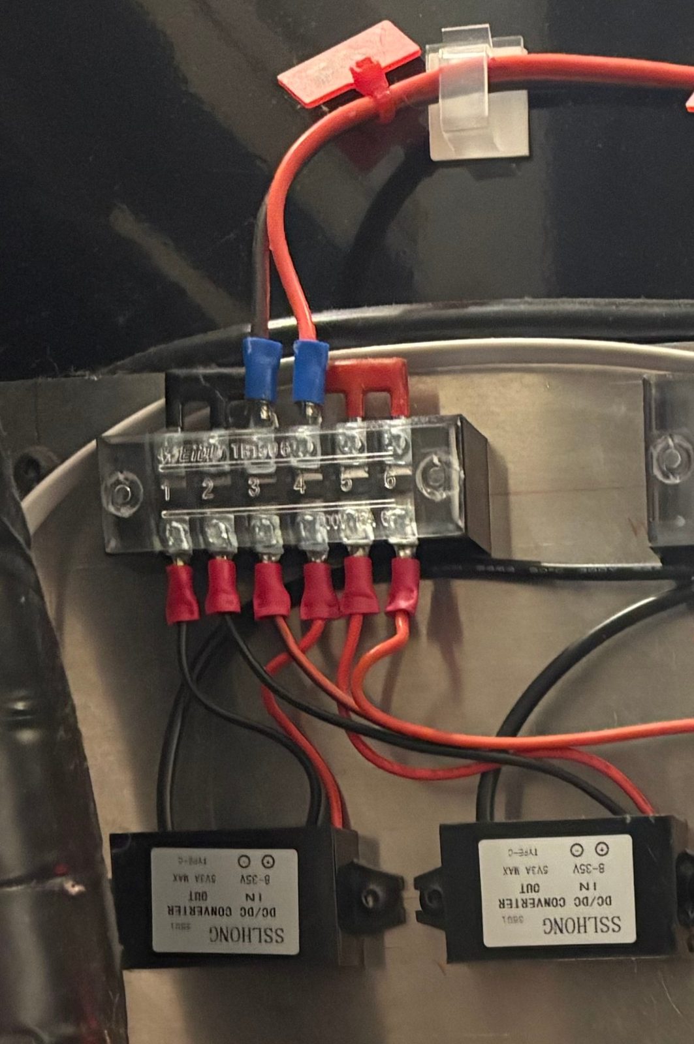
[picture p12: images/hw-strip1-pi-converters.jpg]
Distribution strip 1 and the two Pi buck converters


**Two SSLHONG DC/DC converters**, black potted modules below the strips at the
left: 8–35 V in, 5 V 3 A out on a USB-C plug, fed from strip 1. These power the
two Pis.

**A 6-channel relay module** (red board, blue JQC-3FF-S-Z relays, high/low
level trigger) beside the converters, inputs jumpered from the three BrewPi
Arduinos. **Left three relays: heaters** — `COM` fed from strip 2, `NO` out to
a 6-way barrier block on the back of the workbench, under the power capacitor,
where the cables tagged `H1`, `H2` and `H3` leave for the heaters across the
room. **Right three relays: cooling**, switching 24 V from strip 3 onto strip 4
for the glycol pumps. One heater and one pump relay per fermenter,
matching pins 5 and 6 on each Uno.

**A 10-way barrier strip** to the left of the Uno row, where the three fermenter
probes arrive and are jumpered, with 4.7 kΩ pull-ups, to the three BrewPi Unos
(see [Fermenters](#fermenters)).

**Four Arduino Unos on HCDC screw-terminal shields** in a row across the middle.
Three on the left are the BrewPi controllers, each with a probe on `A0` and two
jumpers up to the relay module. The fourth, right of centre, has a rainbow
ribbon into pins 6–10 and is the RaspberryPints pulse counter. **The two switch
pod Unos are at the bottom left** of the panel, so all six Arduinos are here;
each pod reaches the panel by its signal-and-ground cable to one of those two,
plus a 12 V pair from the dash power module for its lamps.

**An 8-channel relay module** (red board, Songle SRD-05VDC-SL-C relays, high/low
level trigger) on the right, driven by a ribbon from one of the Pis, its
contacts wired to the barrier strips beside it. It is **shared between the two
Pis**: the **top five channels connect and disconnect the five SF800 flow
meters**, driven from `brewpi` GPIO 2, 3, 27, 21 and 13, and the **bottom three
switch 12 V from strip 1 to the `AUTO`, `NORM` and `PURSUIT` lamps**, driven
from `rpints` GPIO 19, 20 and 12. The flow meter relays sit **in the pulse
line**: meter → barrier strip → relay contact → Uno pin, so a disconnected
meter still has power and simply cannot be heard.

**Two Raspberry Pi 4s** across the bottom, each wearing a GeeekPi screw-terminal
GPIO breakout HAT with an LED per pin (`PWR` / `GPIO STATUS`), so a lit LED
shows which outputs are high — handy for checking the tables in
[GPIO, rpints](#gpio-rpints) and [GPIO, brewpi](#gpio-brewpi) against the
panel. Ethernet to both, USB out to the Unos.

**Small relay modules** along the bottom. The **4-channel board** under the
`rpints` Pi switches 12 V to the dash boards — speedo, tacho, dummy6, and both
dummy3s on one channel. **Two single-channel boards stacked together** are the
Pi interlocks in the `POWER` button chain, driven from rpints GPIO 23 and brewpi
GPIO 5 and wired through their NC contacts. At the **far bottom right** a 4-way
terminal block carries the power-switching connections, and beside it is the
**HiLetgo bistable latching relay module** that the `POWER` button triggers and
whose output drives the two D-1012 contactors in the supply box. See
[The Power button](#the-power-button). The barrier strip tagged `PURS`, `AUTO`,
`NORM` beside them is the PANP switch strip (see
[PANP switches](#panp-switches)). The Pursuit-only relay is channel 1 of the
4-channel module.

**Right-hand edge**: three 8-way barrier strips, all fed by the same uxcell
8-core cable. The **upper one is the serving keezer**: one cable carries the
five SF800 flow meters *and* the six keezer probes, and the eight cores are
used exactly:

| Position | Carries |
| --- | --- |
| 1 | 0 V for the SF800s and the one-wire probes — the RaspberryPints Uno's `GND`, also tied to the 3-way block and on to the Pi's ground |
| 2 | **+5 V from the RaspberryPints Uno** — the only power in the keezer, feeding the SF800s and the DS18B20s |
| 3 | one-wire data — the six keezer DS18B20s — pulled up to the **Uno's 3.3 V** through a resistor on the small 3-way block below the relay module — the same blue metal-film part as the two on the 12-way strip, so almost certainly 2.2 kΩ **(confirm with a meter)** — then to `rpints` GPIO 4 |
| 4–8 | SF800 pulse lines for taps 1–5, each to a contact on the 8-way relay module and from there to the RaspberryPints Uno |

The 3-way block is the meeting point: keezer ground, Pi ground and the Uno's
3.3 V for the pull-up. Pulling the bus up to 3.3 V rather than the probes' 5 V
supply is what keeps the data line within the Pi's GPIO range, so the probes can
run on 5 V while the Pi reads them directly.

The **lower two carry the PANP cable** — the button contacts and the 12 V lamp
feeds for the four dash pushbuttons, one cable each (see
[PANP switches](#panp-switches)).

## Relay inventory

Every switched load in the system, and who switches it. The relay boards on the
back panel are the common opto-isolated modules; the exact channel each wire
lands on is only recorded on the panel.

| Switched by | Count | Loads |
| --- | --- | --- |
| BrewPi Unos, pin 5 | 3 | fermenter heaters, 12 V — left three relays of the 6-channel module, strip 1 → strip 2 |
| BrewPi Unos, pin 6 | 3 | glycol pumps, 24 V — right three relays of the 6-channel module, strip 3 → strip 4 |
| brewpi GPIO 2/3/27/21/13 | 5 | flow meter pulse lines 1–5 — five channels of the 8-channel module |
| brewpi GPIO 16 | 1 | message centre power — channel 4 of the SunFounder 4-channel module |
| brewpi GPIO 5 | 1 | `POWER` button interlock — NC contact in series with the button, open while brewpi is up |
| rpints GPIO 10, 18 | 2 | dash board power — channels 3 and 2 of the SunFounder 4-channel module |
| rpints GPIO 17 | 1 | Pursuit-only relay (`sp_power`) — channel 1 of the same module |
| rpints GPIO 23 | 1 | `POWER` button interlock — NC contact in series with the button, open while rpints is up |
| `POWER` button, via the latching module | 2 | the two D-1012 30 A contactors — lower: the switched 12 V rail via the fuse block; upper: the buffer capacitor |
| rpints GPIO 19/20/12 | 3 | PANP lamps — bottom three channels of the 8-channel module |
| A419 ×2 | 2 | keezer compressors — self-contained, not on the panel |

## Parts

The bought-in electronics, as they are identified. Where a listing has since
disappeared the ASIN is still the best handle on exactly which variant it was.

| Part | What it is | Source |
| --- | --- | --- |
| 12 V supply | InstallerCCTV 18-channel 12 VDC 30 A CCTV power distribution box, 360 W, UL listed — gutted; only the enclosure and supply module are in use | [Amazon B08XMKT1F8](https://www.amazon.com/dp/B08XMKT1F8), listing gone |
| Main contactors ×2 | CZH-Labs MD-D1012T/12V, DIN-rail SPST-NO 30 A power relay module (TE T9AS1D12-12 relay), 12 V coil — driven by the latching module, switch the 12 V rail | [Amazon B00UA46BFE](https://www.amazon.com/dp/B00UA46BFE), [czh-labs.com](https://czh-labs.com/products/czh-labs-din-rail-mount-coil-12v-passive-1-channel-spst-no-30a-30amp-power-relay-module) |
| Power latch | HiLetgo 12 V single bistable self-locking relay module, push-to-toggle with external trigger input, 10 A contact; output taken from `NC` | [Amazon B01HHM5M4M](https://www.amazon.com/dp/B01HHM5M4M) |
| Power interlocks ×2 | DC 5 V 1-channel opto-isolated relay module, high/low trigger by jumper, `COM`/`NC` used, powered from each Pi's 5 V, `IN` from IO23 (rpints) and IO5 (brewpi) | [Amazon B079FJSYGY](https://www.amazon.com/dp/B079FJSYGY) |
| Fused distribution | CZH-Labs D-1384, 6-position DIN-rail DC fuse distribution module, ATO/ATC blade fuses, 30 A in, up to 10 A per output, blown-fuse LED per channel | [Amazon B08PT3PXSB](https://www.amazon.com/dp/B08PT3PXSB), [czh-labs.com](https://czh-labs.com/products/din-rail-mount-6-position-dc-power-fuse-distribution-strip-module) |
| 24 V converter | MGGi DC 12 V→24 V boost converter, 15 A, 360 W, IP68 potted aluminium case; mounted on top of the supply box | [Amazon B09TB35ZGD](https://www.amazon.com/dp/B09TB35ZGD) |
| Workbench | Kobalt 45 in W × 36 in H three-drawer hardwood workbench with pegboard back — the dash is cut into the pegboard, the electronics hang behind it | [Lowe's 1002624252](https://www.lowes.com/pd/Kobalt-45-in-W-x-36-in-H-3-Drawer-Hardwood-Work-Bench/1002624252) |
| PANP switches ×4 | Honeywell MICRO SWITCH illuminated pushbutton, marked 4A13BAA31, 5 A 250 VAC contacts, 28 V lamp — supplied with the dash by ideegeniali | — |
| Level shifters ×2 | TXS0108E 8-channel bidirectional logic level converter module, 3.3 V side to the Pi, 5 V side to the dash serial lines, `OE` from GPIO 25; one per Pi | [Amazon B09XH4PV5J](https://www.amazon.com/dp/B09XH4PV5J) |
| Field cable ×3 | uxcell RVV 8-core 20 AWG stranded PVC cable, 300 V, 3 m — PANP contacts, PANP lamps, and the SF800 flow meters | [Amazon B07RHV4WNV](https://www.amazon.com/dp/B07RHV4WNV) |
| Pi power ×2 | SSLHONG DC 12/24 V to 5 V 3 A 15 W USB-C step-down buck module, 8–35 V in, epoxy potted | [Amazon B07ZQB6S3L](https://www.amazon.com/dp/B07ZQB6S3L) |
| Fermenter relays | ANMBEST 6-channel 5 V opto-isolated relay module, 10 A contacts, high/low level trigger by jumper | [Amazon B08RRTHTYQ](https://www.amazon.com/dp/B08RRTHTYQ) |
| Flow meter and PANP lamp relays | HiLetgo 5 V 8-channel opto-isolated relay module, Songle SRD-05VDC-SL-C relays, high/low level trigger | [Amazon B00LX3UH9C](https://www.amazon.com/dp/B00LX3UH9C) |
| Dash power relays | SunFounder 5 V 4-channel relay module — speedo, tacho, dummy6, both dummy3s | [Amazon B00E0NSORY](https://www.amazon.com/dp/B00E0NSORY) |
| Fermenter heaters ×2 | SS Brewtech legacy FTSs heater pad, 60 W, 12 V, barrel jack — chronical and unitank-2 | [ssbrewtech.com](https://www.ssbrewtech.com/products/heater-pad-60w-for-chronical) |
| Fermenter heater ×1 | SS Brewtech FTSs Touch heating pad, 12 V, XT30 connector, SKU HTR180WXT — unitank-1 | [ssbrewtech.com](https://www.ssbrewtech.com/products/ftss-touch-chronical-and-unitank-heating-pad) |
| Buffer capacitor | Belva BB1D 1 farad car-audio power capacitor with voltmeter display, across the 12→24 V converter's 12 V input via the upper D-1012 and an inline fuse | — |
| Glycol pumps ×4 | Penguin Chillers XL glycol pump, 24 VDC, 55 W, 6 GPM max, 50 ft head, 3/8" or 1/2" fittings — three on BrewPi relays from the 24 V bus, one always on for the draft trunk line from its own Penguin mains adapter | [penguinchillers.com](https://penguinchillers.com/products/glycol-pumps) |
| Glycol chillers ×2 | SS Brewtech 1/5 hp glycol chiller, 1450 BTU/h, 4.75 gal reservoir, 120 VAC — set to 23 °F (unitanks) and 26 °F (chronical and trunk line) | [ssbrewtech.com](https://www.ssbrewtech.com/products/glycol-chiller-1-5hp) |
| Temperature probes | HiLetgo DS18B20, stainless steel waterproof probe on 1 m lead — red VCC, yellow data, black GND | [Amazon B00M1PM55K](https://www.amazon.com/dp/B00M1PM55K) |
| Arduino shields ×6 | HCDC screw terminal block breakout shield for Arduino Uno R3 — 3.5 mm terminals, 26–16 AWG, IDC40 header, power LED, reset button, ICSP pass-through | [Amazon B08LH5TCM5](https://www.amazon.com/dp/B08LH5TCM5) |
| Pi GPIO breakouts ×2 | GeeekPi GPIO screw terminal block breakout HAT with per-pin status LEDs — 3.5 mm terminals, 26–16 AWG; LED matrix mirrors the 2×20 header, light blue for GPIO, dark blue for special-function pins, red 5 V, pink 3.3 V | [Amazon B08GKQMC72](https://www.amazon.com/dp/B08GKQMC72) |
| Barrier strips | dual-row covered screw barrier strips, a mixture of: 6-way 600 V 25 A ([B07CLY5N9T](https://www.amazon.com/dp/B07CLY5N9T), [mxuteuk TB-2506 B0869D8B5Z](https://www.amazon.com/dp/B0869D8B5Z)); 8-way 600 V 15 A ([uxcell TB-1508L B07DM2T59R](https://www.amazon.com/dp/B07DM2T59R)); 4-way 600 V 25 A ([mxuteuk TB-2504 B0869CYWSC](https://www.amazon.com/dp/B0869CYWSC)) and 15 A ([mxuteuk TB-1504 B0869CYC2K](https://www.amazon.com/dp/B0869CYC2K)); 12-way 600 V 15 A ([B07CLW5FPS](https://www.amazon.com/dp/B07CLW5FPS)) | see left |

## Still to confirm

Everything above has been walked with the owner. What is left is small, and
each item is also marked **(confirm)** where it comes up:

1. **Panel one-wire buses** — that the lager and hot-side probes really are in
   parasite-power mode (`VDD` to ground at the probe), and a meter reading of
   the 2.2 kΩ pull-ups.
2. **The keezer pull-up** — a meter reading of the resistor on the 3-way block;
   it looks like the same 2.2 kΩ part as the other two.
3. **rpints shifter channels** — which of `A6`/`B6` and `A7`/`B7` carries the
   tacho and which the dummy bus.

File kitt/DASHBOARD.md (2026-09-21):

# What the dashboard is actually telling you

The dash carries KITT's original season 2 labels — inlet temperature, hydraulic
system stress, propagation delay. None of them mean what they say. This is the
decoder ring.

Each section below shows the panel as KITT has it — the labels are set in
Eurostyle Extended, the typeface the show used — beside what the brewery
actually puts behind them. The photographs are of this dash, taken in
September 2026 with `panp.py` stopped and every bar, LED and segment driven
full from a script, at Norm brightness so the camera did not saturate. They
are a truthful reference for LED counts and colours.

[`images/s2-dash.png`](../images/s2-dash.png) is a high-resolution scan of
the season 2 panel artwork this hardware reproduces. It is useful for the
labels, but it is artwork rather than a photograph and has at least one error:
it draws **15** LEDs on the line above the multifunction display where the
real board has **16**. Don't count LEDs off the scan; count them off the
photographs or the hardware.

Letters in parentheses are the board's serial address — see
[README.md](README.md) for the protocol and [`panp/panp.py`](panp/panp.py) for
the code.

## Speedo cluster (B)

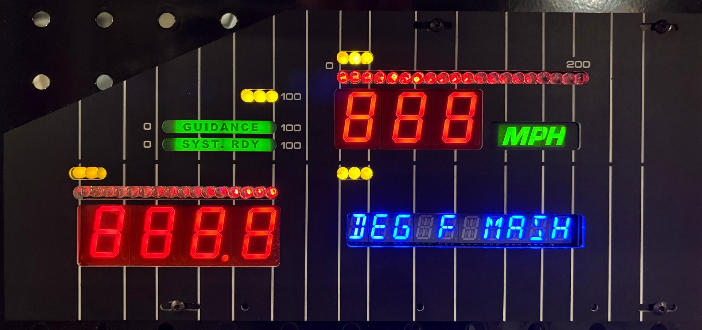
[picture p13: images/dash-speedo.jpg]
Speedo cluster, every segment lit, with the message centre beside the lower display


| KITT label | Brewery value |
| --- | --- |
| `MPH`, 3 digits | **HLT temperature**, °F, rounded to whole degrees |
| bargraph above `MPH` | the same HLT temperature — 20 LEDs on 19 addressable steps of 10 °F, one step lighting two LEDs, so 160 °F lights 17 and the line is full at 190 °F |
| `000.0`, 4 digits | **the selected value** — whatever the left switch pod last chose |
| 16-LED bargraph above it | the same selected value, scaled to its own range — 16 LEDs on 13 addressable steps, three steps lighting two LEDs; each mode's span runs from dark to full over those 13 steps |
| `GUIDANCE`, `SYST. RDY` | unused |
| alphanumeric row | the message center — see below |

The lower display is the multi-function one. What it shows, and the scale the
bargraph uses, both depend on the left switch pod:

| Showing | Bargraph spans | Decimal |
| --- | --- | --- |
| mash tun temperature | dark at 110 °F, full at 190 °F | `000.0` |
| HLT temperature | dark at 110 °F, full at 190 °F | `000.0` |
| unitank 1, unitank 2 or chronical temperature | dark at 34 °F, full at 82 °F | `000.0` |
| any of those three gravities | dark at 1.000, full at 1.064 | `0.000` |
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

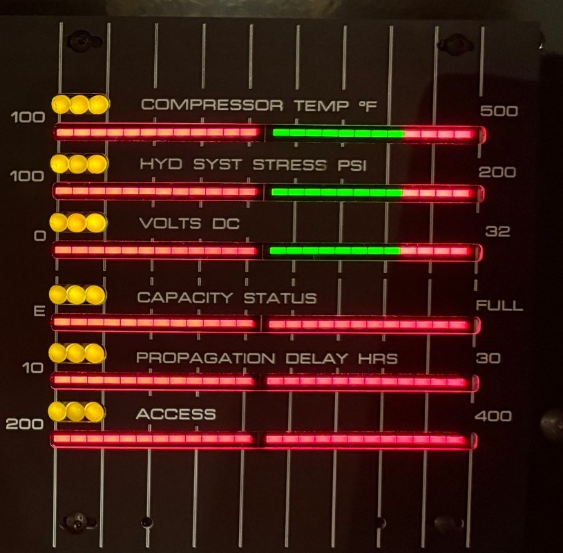
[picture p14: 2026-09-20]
images/dash-dummy6.jpg

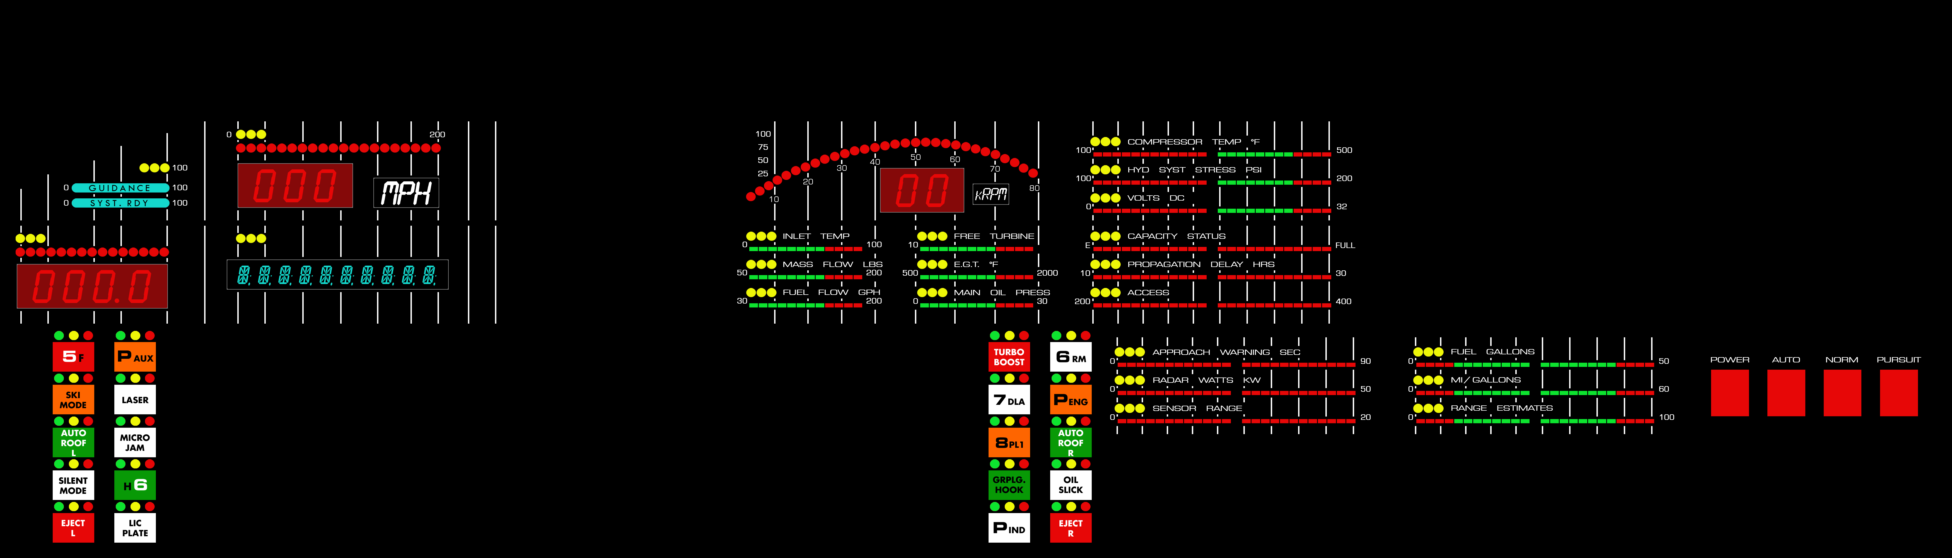
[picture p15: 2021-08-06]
images/s2-dash.png

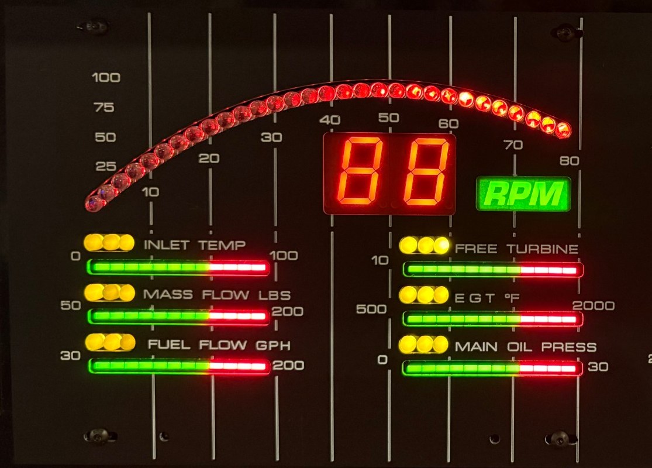
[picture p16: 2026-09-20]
images/dash-tacho.jpg

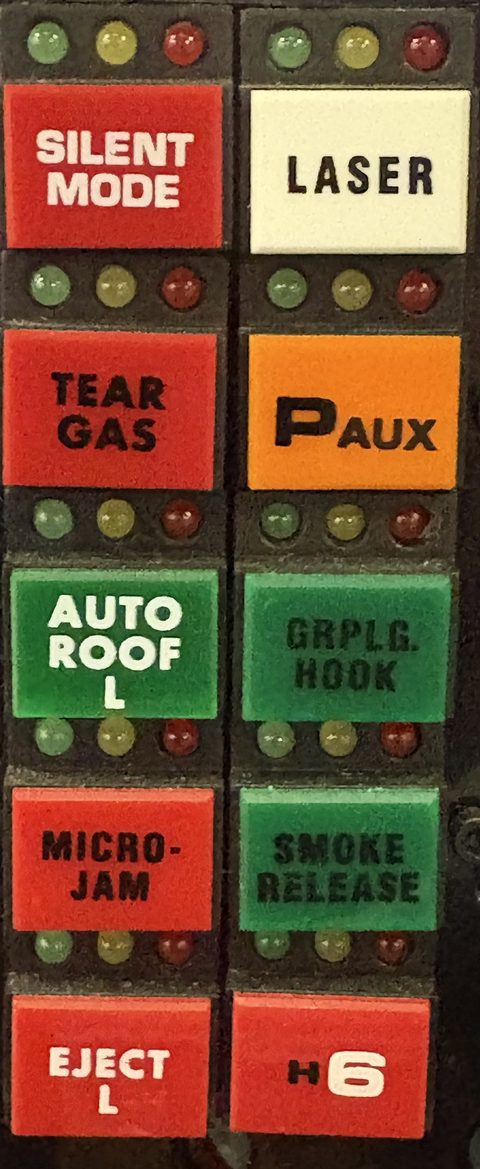
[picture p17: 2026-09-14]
images/switchpod-left.jpg

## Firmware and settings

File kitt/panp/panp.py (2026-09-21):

#!/usr/bin/python3

"""Drive the KITT dash from brewery data.

One script runs on both Raspberry Pis and decides which it is from the
hostname: `rpints` owns the PANP buttons, the dash power relays, the tacho and
the two dummy boards; `brewpi` owns the speedo, the message centre and the
flow meter relays. See kitt/README.md for how it fits together and
kitt/DASHBOARD.md for what every gauge means.
"""

import json
import math
import os
import signal
import socket
import ssl
import statistics
import sys
import threading
import time
import urllib.request
from enum import Enum
from queue import Queue
from threading import Thread

import mysql.connector as database
import RPi.GPIO as GPIO
import sdnotify
import serial
from serial.serialutil import PortNotOpenError


# ---------------------------------------------------------------------------
# Pins (board numbering)
# ---------------------------------------------------------------------------

# common to both hosts
SERIAL_ENABLE = 22        # GPIO 25, enables the 3.3V to 5V serial converter
AUTO_MODE_COMM = 26       # GPIO 7 (CE1), rpints tells brewpi it is in auto
NORMAL_MODE_COMM = 15     # GPIO 22, rpints tells brewpi it is in norm

# rpints
LOWER_DASH_POWER = 19     # GPIO 10 (MOSI)
UPPER_DASH_POWER = 12     # GPIO 18
SP_POWER = 11             # GPIO 17

# brewpi
MSGCTR_POWER = 36         # GPIO 16
FLOWMETER = [3, 5, 13, 40, 33]   # GPIO 2 (SCL), 3 (SDA), 27, 21, 13


class PANPState(Enum):
    """PANP lamps, by pin."""
    AUTO = 35       # GPIO 19
    NORM = 38       # GPIO 20
    PURSUIT = 32    # GPIO 12


class PANPButton(Enum):
    """PANP buttons, by pin."""
    AUTO = 29       # GPIO 5
    NORM = 31       # GPIO 6
    PURSUIT = 36    # GPIO 16


# ---------------------------------------------------------------------------
# Timing and cadence
# ---------------------------------------------------------------------------

SERIAL_GAP = 0.1          # the boards drop messages sent closer together than this
LOOP_PERIOD = 0.25        # seconds between passes of the main loop
STARTUP_SETTLE = 3        # seconds for the threads to start before the first pass
DATABASE_EVERY = 11       # passes between RaspberryPints queries
PROBE_PERIOD = 1          # seconds between one-wire probe reads
PROBE_MISSES = 10         # failed reads in a row before a probe is shown as 0.0
BREWPI_PERIOD = 60        # seconds between BrewPi Remix polls
SWITCHPOD_RETRY = 2       # seconds before reopening a switchpod that went away
BRIGHTNESS_REPEATS = 3    # a brightness message is sent this many times

BAUD = 57600


# ---------------------------------------------------------------------------
# Probes and fermenters
# ---------------------------------------------------------------------------

# the six serving keezer probes, in the order the tacho bars show them
KEEZER_PROBES = [
    "/sys/bus/w1/devices/28-012052b92541/w1_slave",
    "/sys/bus/w1/devices/28-012058f936f3/w1_slave",
    "/sys/bus/w1/devices/28-012052ba8dab/w1_slave",
    "/sys/bus/w1/devices/28-012058fbceb5/w1_slave",
    "/sys/bus/w1/devices/28-012058fc2851/w1_slave",
    "/sys/bus/w1/devices/28-012052b426ca/w1_slave"]

# the three lager fridge probes
LAGER_PROBES = [
    "/sys/bus/w1/devices/28-3c01b556f6d0/w1_slave",
    "/sys/bus/w1/devices/28-3cdd04574813/w1_slave",
    "/sys/bus/w1/devices/28-3ce80457395a/w1_slave"]

# mash tun, then hot liquor tank
HOT_SIDE_PROBES = [
    "/sys/bus/w1/devices/28-012052b65be5/w1_slave",
    "/sys/bus/w1/devices/28-0120529d8f20/w1_slave"]

# the BrewPi Remix instances, each with a KITTSOCKET in its home directory
FERMENTERS = ["unitank-1", "unitank-2", "chronical"]


# ---------------------------------------------------------------------------
# Display modes
# ---------------------------------------------------------------------------

class TachoView(Enum):
    """What the tacho digits and arc show."""
    MEAN = 0          # mean of the six serving keezer probes
    KEG_PINTS = 1     # the selected keg: imperial pints left on the digits, percent full on the arc
    KEG_GALLONS = 2   # the same keg, US gallons to a tenth on the digits
    LAGER_TEMP = 3    # the selected lager probe


class MsgCtrMode(Enum):
    """What the lower speedo display shows, and so what the message centre captions."""
    MASH_TEMP = 0
    HLT_TEMP = 1
    UNITANK1_TEMP = 2
    UNITANK1_SG = 3
    UNITANK2_TEMP = 4
    UNITANK2_SG = 5
    CHRONICAL_TEMP = 6
    CHRONICAL_SG = 7
    BREWPI_UP = 8
    MASH_TEMP_C = 9   # no button selects this
    FLOWMETER = 10


class TankDisplay(Enum):
    """Which of temperature and gravity a fermenter button shows on its next press."""
    TEMP = 0
    SG = 1


# right switch pod, left column: position -> keg 1-5 as an index. each press
# steps the tacho through that keg's views, in KEG_VIEWS order, and the press
# after the last goes back to the mean. the probes' own temperatures are not
# offered: the keezer's airflow keeps them equal, and the six bars show any
# one that is not
RIGHT_POD_KEGS = {
    0: 0,   # TURBO BOOST
    2: 1,   # 7 DLA
    4: 2,   # 8 PL1
    6: 3,   # 6 RM (orange)
    8: 4,   # H6
}
KEG_VIEWS = [TachoView.KEG_PINTS, TachoView.KEG_GALLONS]

# right switch pod, right column: position -> lager probe as an index. one
# press shows it, the next goes back to the mean
RIGHT_POD_LAGERS = {
    1: 0,   # 6 RM (white)
    3: 1,   # P ENG
    5: 2,   # AUTO ROOF R
}

# right switch pod, right column: the brewery room lights over the hue bridge
RIGHT_POD_LIGHTS_ON = 7    # P IND
RIGHT_POD_LIGHTS_OFF = 9   # EJECT R

# each tap's keg when full, in US gallons: four kegs and, on tap 5, the 2.5
# gallon cask on the beer engine. RaspberryPints reports volumes in gallons
KEG_GALLONS = [5.0, 5.0, 5.0, 5.0, 2.5]
# imperial pints in a US gallon: 3785.411784 ml over 568.26125 ml
PINTS_PER_GALLON = 3785.411784 / 568.26125

# the arc shows a keg's percent full, and is full from this percentage up
ARC_FULL_PERCENT = 80.0

# left switch pod, left column: position -> a fixed caption
LEFT_POD_CAPTIONS = {
    0: (MsgCtrMode.MASH_TEMP, ">CScDEG F MASH?"),   # SILENT MODE
    2: (MsgCtrMode.HLT_TEMP, ">CScDEG F HLT?"),     # TEAR GAS
}

# left switch pod, left column: position -> a fermenter that alternates
# temperature and gravity: (tank index, temperature mode, gravity mode, name)
LEFT_POD_TANKS = {
    4: (0, MsgCtrMode.UNITANK1_TEMP, MsgCtrMode.UNITANK1_SG, "UTK1"),   # AUTO ROOF L
    6: (1, MsgCtrMode.UNITANK2_TEMP, MsgCtrMode.UNITANK2_SG, "UTK2"),   # MICRO-JAM
    8: (2, MsgCtrMode.CHRONICAL_TEMP, MsgCtrMode.CHRONICAL_SG, "CHRN"),  # EJECT L
}

# left switch pod, right column: position -> flow meter relay to toggle
LEFT_POD_FLOWMETERS = {
    1: 0,   # LASER
    3: 1,   # PAUX
    5: 2,   # GRPLG. HOOK
    7: 3,   # SMOKE RELEASE
    9: 4,   # H6
}


# The speedo's two led lines take a step count, and the board clamps it to the
# line's own maximum. Neither line is one led per step: some steps light a
# pair. Measured on the board, September 2026.
SPEED_LINE_STEPS = 19     # 20 leds above MPH, one step lights two
FUEL_LINE_STEPS = 13      # 16 leds above the multifunction display, three steps light two


def _span(lo, hi):
    """Steps to light on the multifunction line for a value on a linear scale.

    Dark at `lo`, full at `hi`, whatever the line's step count is.
    """
    return lambda value: (value - lo) / (hi - lo) * FUEL_LINE_STEPS


# what the lower speedo display shows in each mode: the value, the multifunction
# line's span for it, and the decimal point position (1 is 000.0, 3 is 0.000).
# gravities arrive already multiplied by 100, so 1.050 is 105.0 here
LOWER_DISPLAY = {
    MsgCtrMode.MASH_TEMP:      (lambda h: h.hot_side_temps[0], _span(110.0, 190.0), 1),
    MsgCtrMode.MASH_TEMP_C:    (lambda h: (h.hot_side_temps[0] - 32.0) * 5.0 / 9.0, _span(20.0, 84.0), 1),
    MsgCtrMode.UNITANK1_TEMP:  (lambda h: h.brewpi_rmx_data[0], _span(34.0, 82.0), 1),
    MsgCtrMode.UNITANK2_TEMP:  (lambda h: h.brewpi_rmx_data[2], _span(34.0, 82.0), 1),
    MsgCtrMode.CHRONICAL_TEMP: (lambda h: h.brewpi_rmx_data[4], _span(34.0, 82.0), 1),
    MsgCtrMode.BREWPI_UP:      (lambda h: h.hot_side_temps[0], _span(45.0, 205.0), 1),
    MsgCtrMode.HLT_TEMP:       (lambda h: h.hot_side_temps[1], _span(110.0, 190.0), 1),
    MsgCtrMode.UNITANK1_SG:    (lambda h: h.brewpi_rmx_data[1] * 100.0, _span(100.0, 106.4), 3),
    MsgCtrMode.UNITANK2_SG:    (lambda h: h.brewpi_rmx_data[3] * 100.0, _span(100.0, 106.4), 3),
    MsgCtrMode.CHRONICAL_SG:   (lambda h: h.brewpi_rmx_data[5] * 100.0, _span(100.0, 106.4), 3),
}

# the message centre's own rotation while the dash is dark
MSGCTR_IDLE = ">CSbBREWPI UP|BREWPI UP~?"


# ---------------------------------------------------------------------------
# Bar graph scaling
# ---------------------------------------------------------------------------
#
# Each bar takes a single byte and lights that many segments. These lists map a
# temperature or a percentage onto the byte values that land on consecutive fill
# steps; tuning the dash means editing them. See kitt/DASHBOARD.md for the
# segment counts and colour layouts they are written against.

# the tacho's rpm arc, 30 leds, one per step: the step number is sent raw
RPM_CIRCLE_TEMPS = [2.0, 4.0, 6.0, 8.0, 10.0,
                    12.5, 15.0, 17.5, 20.0,
                    22.5, 25.0, 27.5, 30.0,
                    33.0, 36.0, 40.0,
                    43.0, 46.0, 49.0,
                    52.5, 55.0, 57.5, 60.0,
                    62.5, 65.0, 67.5, 70.0,
                    72.5, 75.0, 77.5, 80.0]

# the six tacho bars, 8 steps landing on steps 1-8, so never fully dark
TACHO_BAR_TEMPS = [30.0, 33.0, 36.0, 39.0, 43.0, 47.0, 48.0, 51.0]
TACHO_BAR_VALUES = [0x20, 0x38, 0x54, 0x70, 0x90, 0xA8, 0xC4, 0xE0]

# the dummy bars take 16 steps; these 17 values land on steps 0-16
DUMMY_BAR_VALUES = [0x00, 0x10, 0x20, 0x30, 0x40, 0x50,
                    0x60, 0x70, 0x79, 0x88, 0x97,
                    0xA6, 0xB5, 0xC4, 0xD3, 0xE2, 0xFF]

# keg volume, as a percentage of the starting volume
KEG_BAR_VOLS = [4.1, 12.3, 16.4, 24.6, 32.8,
                36.9, 45.1, 49.9, 53.3, 61.5, 65.6,
                73.8, 82.0, 86.1, 94.3, 98.0, 99.9]

# lager fridge temperature
LAGER_BAR_TEMPS = [23.5, 24.0, 25.0, 26.5, 27.5,
                   28.0, 29.0, 29.5, 30.0, 30.5,
                   31.0, 31.5, 32.5, 33.5, 34.0, 35.0, 35.5]

# fermenter temperature; steps 1-16 of the dummy values, so never fully dark
TEMPERATURE_BAR_TEMPS = [30.0, 34.0, 37.0, 41.0, 44.0,
                         46.0, 50.0, 52.0, 54.0, 58.0, 60.0,
                         64.0, 68.0, 70.0, 74.0, 76.0]
TEMPERATURE_BAR_VALUES = DUMMY_BAR_VALUES[1:]


def step(value, thresholds):
    """Index of the first threshold the value is below.

    Falling off the end clamps to the last index on purpose, so a value above
    the top of the list shows a full bar.
    """
    for i, t in enumerate(thresholds):
        if value < t:
            break
    return i


def rpm_circle(temp):
    return step(temp, RPM_CIRCLE_TEMPS)


def arc_percent(percent):
    """Arc steps for a keg's percent full: dark at empty, all 30 from ARC_FULL_PERCENT up."""
    steps = int(percent / ARC_FULL_PERCENT * len(RPM_CIRCLE_TEMPS[:-1]))
    return max(0, min(len(RPM_CIRCLE_TEMPS[:-1]), steps))


def digit_byte(value):
    """A value for the tacho's two digits as a register byte; over 99 the board shows HI.

    Rounds halves up, so 1.25 gallons reads 1.3 rather than Python's 1.2.
    """
    return max(0, min(255, int(math.floor(value + 0.5))))


def tacho_bar(temp):
    return TACHO_BAR_VALUES[step(temp, TACHO_BAR_TEMPS)]


def keg_bar(vol):
    return DUMMY_BAR_VALUES[step(vol, KEG_BAR_VOLS)]


def lager_bar(temp):
    return DUMMY_BAR_VALUES[step(temp, LAGER_BAR_TEMPS)]


def temperature_bar(temp):
    return TEMPERATURE_BAR_VALUES[step(temp, TEMPERATURE_BAR_TEMPS)]


def temperature_digits(value):
    """Split a value into the hundreds, tens, ones and tenths digits the speedo wants."""
    tenths = int(round(value % 1 * 10.0, 0))
    ones = int(value % 10)
    tens = int(value // 10 % 10)
    hundreds = int(value // 100 % 10)
    return hundreds, tens, ones, tenths


# ---------------------------------------------------------------------------
# Plumbing
# ---------------------------------------------------------------------------

def drain(q):
    """Yield everything queued so far without blocking."""
    while q.qsize() > 0:
        yield q.get()


class Wire:
    """Hands out turns to transmit to the dash, first come first served.

    One of these is shared by both buses on a Pi, and every packet on either
    bus takes a turn and waits SERIAL_GAP before going out. That buys two
    things. The boards drop packets that follow another on the same bus by
    less than the gap. And the two buses are neighbouring channels of one
    level shifter on long cable runs, so a packet on one is corrupted when the
    other is transmitting at the same instant; with a single gate that cannot
    happen.

    Turns are served in the order they were asked for. A plain lock lets the
    thread that just released it take it straight back, so a burst of writes
    from the GPIO callback thread would hold the main loop off the bus for
    seconds; with tickets the two interleave packet by packet.
    """

    def __init__(self):
        self.cond = threading.Condition()
        self.next_ticket = 0
        self.serving = 0

    def __enter__(self):
        with self.cond:
            ticket = self.next_ticket
            self.next_ticket += 1
            while self.serving != ticket:
                self.cond.wait()

    def __exit__(self, *exc):
        with self.cond:
            self.serving += 1
            self.cond.notify_all()


class Bus:
    """One serial bus to the dash. All writes go through the shared Wire.

    `boards` is the destination letters of the boards strapped to this bus,
    as traced in HARDWARE.md; a message for any other board need not be sent
    on it.
    """

    def __init__(self, device, wire, boards):
        self.port = serial.Serial(device, BAUD)
        self.wire = wire
        self.boards = boards

    def write(self, msg):
        with self.wire:
            time.sleep(SERIAL_GAP)
            self.port.write(msg.encode())

    def close(self):
        self.port.close()


class Service:
    """Process-wide state: systemd, the shutdown flag, and what to close on exit."""

    def __init__(self):
        self.hostname = socket.gethostname()
        self.pid = os.getpid()
        self.notifier = sdnotify.SystemdNotifier()
        self.running = False
        self.wire = Wire()
        self.buses = []
        self.teardown = None
        # objects whose bound methods are GPIO callbacks; kept so they stay alive
        self.handlers = []

    def status(self, msg):
        print(msg)
        self.notifier.notify(f"STATUS={msg}")

    def open_bus(self, device, boards):
        bus = Bus(device, self.wire, boards)
        self.buses.append(bus)
        return bus

    def sigterm(self, _signo, _frame):
        self.running = False
        self.status(f"PANP service PID {self.pid} on {self.hostname} got SIGTERM")
        if self.teardown is not None:
            self.teardown()
        GPIO.output(SERIAL_ENABLE, 0)
        self.shutdown()

    def shutdown(self):
        """Close the ports and leave. Does not return."""
        self.status(f"PANP service on {self.hostname} shutting down")
        time.sleep(1)
        for bus in reversed(self.buses):
            bus.close()
        self.status(f"PANP service on {self.hostname} exiting cleanly")
        self.notifier.notify("STOPPING=1")
        sys.exit(0)


# ---------------------------------------------------------------------------
# Background readers, each a daemon thread feeding a queue
# ---------------------------------------------------------------------------

def read_probe_f(path):
    """Temperature of a one-wire probe in degrees F, or None if it cannot be read.

    The kernel reports the CRC of the reading on the first line; a reading
    that failed its CRC is treated as no reading.
    """
    try:
        with open(path, 'r') as fileobj:
            lines = fileobj.readlines()
        if 'YES' not in lines[0]:
            return None
        equals_pos = lines[1].find('t=')
        tempstr = lines[1][equals_pos + 2:]
        tempvalue_c = float(tempstr) / 1000.0
        return tempvalue_c * 9.0 / 5.0 + 32.0
    except Exception:
        return None


def get_temps(probes, q):
    """Queue (index, temperature) for each probe, once a second.

    A read that fails is skipped, so the display keeps the last good value:
    the one-wire line hiccups for a second now and then and every probe on it
    comes back empty together, which used to paint zeros across the dash. A
    probe that fails PROBE_MISSES reads in a row is reported as 0.0, so one
    that has really gone still shows.
    """
    misses = [0] * len(probes)
    while True:
        try:
            for i, path in enumerate(probes):
                temp = read_probe_f(path)
                if temp is None:
                    misses[i] += 1
                    if misses[i] < PROBE_MISSES:
                        continue
                    temp = 0.0
                else:
                    misses[i] = 0
                q.put((i, temp))
        except Exception:
            pass
        time.sleep(PROBE_PERIOD)


def get_switchpod(sp_q, service):
    """Queue the position of each switchpod key press."""
    path = "/dev/switchpod"
    rx = None
    while True:
        try:
            if rx is None:
                while os.access(path, os.R_OK) is False:
                    time.sleep(1)
                rx = serial.Serial(path, 9600, timeout=None)
            data = rx.readline().decode().strip()
            if not data:
                # switchpod firmware before 2026-09 wrapped the line every
                # twentieth press; harmless, so skip instead of erroring
                continue
            sp_q.put(int(data))
        except Exception:
            # either the input did not parse or the adapter went away. drop
            # the port and pick it up from scratch, waiting for it to exist.
            # the sleep matters: without it a missing device spins the cpu
            try:
                rx.close()
            except Exception:
                pass
            rx = None
            time.sleep(SWITCHPOD_RETRY)
            service.status(f"PANP service PID {service.pid} on {service.hostname} "
                           "restarting switchpod i/o")


def get_brewpi_rmx_data(q):
    """Queue (index, value) for each fermenter's temperature and gravity.

    Index is 2 * fermenter for the temperature and 2 * fermenter + 1 for the
    gravity. A fermenter that cannot be reached reports 0.0 for both. The
    temperature comes back as the text BrewPi shows on its lcd, which is
    "--.-" for a probe it cannot read; the consumer deals with that.
    """
    while True:
        for i, fermenter in enumerate(FERMENTERS):
            for j, request in enumerate(["lcd", "statusText"]):
                data = 0.0
                try:
                    s = socket.socket(socket.AF_UNIX, socket.SOCK_STREAM)
                    s.connect(f"/home/brewpi/{fermenter}/KITTSOCKET")
                    s.sendall(request.encode())
                    s.settimeout(2)
                    try:
                        reply = json.loads(s.recv(4096).decode())
                        if request == "lcd":
                            data = reply[1].split()[1]
                        else:
                            data = reply["0"]["Tilt SG: "]
                    except Exception:
                        pass
                    s.close()
                except Exception:
                    try:
                        s.close()
                    except Exception:
                        pass
                q.put((i * 2 + j, data))
        time.sleep(BREWPI_PERIOD)


# ---------------------------------------------------------------------------
# The bench light
# ---------------------------------------------------------------------------
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

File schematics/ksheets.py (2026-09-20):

"""KiCad schematics for the brew-utils hardware, generated from the wiring
recorded in HARDWARE.md.  Run:  python3 ksheets.py OUTDIR

Coordinates are in grid units of 1.27 mm via g(); the sheets are A3.
Nets that cross sheets use global labels with the same name on each sheet.
"""
import os
import sys
from kicadgen import Schematic, stock, box_symbol

OUT = sys.argv[1] if len(sys.argv) > 1 else os.path.dirname(os.path.abspath(__file__))
os.makedirs(OUT, exist_ok=True)


def g(n):
    return round(n * 1.27, 4)


def G(x, y):
    return (g(x), g(y))


def snapx(v):
    return round(round(v / 1.27) * 1.27, 4)


# ---------------------------------------------------------------- symbols
FUSE = stock('Device', 'Fuse')
CAP = stock('Device', 'C_Polarized')
RES = stock('Device', 'R')
SW = stock('Switch', 'SW_Push')
LAMP = stock('Device', 'Lamp')
TB = {n: stock('Connector', f'Screw_Terminal_01x{n:02d}') for n in (4, 6, 8, 12)}

PSU = box_symbol('PSU_12V_30A', left=['L', 'N'], right=['+12V', '0V'], ref='PS')
LATCH = box_symbol('HiLetgo_Latching_Relay', left=['+12', '0V', 'TRIG', 'TRIG_RTN'], right=['COM', 'NC', 'NO'], ref='K')
OPTO1 = box_symbol('Relay_Module_1ch_5V', left=['IN', 'VCC', 'GND', 'COM'], right=['NC', 'NO'], ref='K')
D1012 = box_symbol('CZH_D-1012_30A', left=['IN+', 'IN-', 'COM'], right=['NO'], ref='K')
D1384 = box_symbol('CZH_D-1384_Fuse_Block', left=['V+', 'V-'],
                   right=['V1:7.5A', 'V2:5A', 'V3:7.5A', 'V4:7.5A', 'V5:7.5A', 'V6:5A'], ref='FB')
MGGI = box_symbol('MGGi_12-24V_15A', left=['IN+', 'IN-'], right=['OUT+', 'OUT-'], ref='U')
PI_R = box_symbol('RPi4_rpints_HAT', right=['IO5', 'IO6', 'IO16', 'IO19', 'IO20', 'IO12', 'IO17', 'IO18', 'IO10',
                                            'IO23', 'IO7', 'IO22', 'IO4', 'IO26', 'TXD', 'CE0', 'IO25', '5V', '3V3', 'GND'], ref='PI')
PI_B = box_symbol('RPi4_brewpi_HAT', right=['IO2', 'IO3', 'IO27', 'IO21', 'IO13', 'IO16', 'IO5', 'IO7', 'IO22',
                                            'IO4', 'TXD', 'CE0', 'IO25', '5V', '3V3', 'GND'], ref='PI')
RELAY8 = box_symbol('Relay_Module_8ch_5V', left=[f'IN{i}' for i in range(1, 9)] + ['VCC', 'GND'],
                    right=sum([[f'COM{i}', f'NO{i}'] for i in range(1, 9)], []), ref='K')
RELAY6 = box_symbol('Relay_Module_6ch_5V', left=[f'IN{i}' for i in range(1, 7)] + ['VCC', 'GND'],
                    right=sum([[f'COM{i}', f'NO{i}'] for i in range(1, 7)], []), ref='K')
RELAY4 = box_symbol('Relay_Module_4ch_5V_LowTrigger', left=[f'IN{i}' for i in range(1, 5)] + ['VCC', 'GND'],
                    right=sum([[f'COM{i}', f'NO{i}'] for i in range(1, 5)], []), ref='K')
UNO_RP = box_symbol('Uno_RaspberryPints', left=['D6', 'D7', 'D8', 'D9', 'D10'], right=['5V', '3V3', 'GND'], ref='A')
UNO_SP = box_symbol('Uno_Switchpod', left=['A0'], right=['5V', 'GND'], ref='A')
UNO_BP = box_symbol('Uno_BrewPi', left=['A0', '5V', 'GND'], right=['D5', 'D6'], ref='A')
POD = box_symbol('Switch_Pod_Ladder', right=['SGN', 'GND', '+12V', '0V'], ref='SP')
SHIFT = box_symbol('TXS0108E', left=['VA', 'A6', 'A7', 'OE', 'GND'], right=['VB', 'B6', 'B7'], ref='U')
PROBES = box_symbol('DS18B20_bus', right=['VDD', 'DQ', 'GND'], ref='T')
BUCK = box_symbol('SSLHONG_12-5V_USB-C', left=['IN+', 'IN-'], right=['USB-C'], ref='U')
BOARD = box_symbol('KITT_dash_board', left=['+12V', 'GND', 'COM'], ref='DB')
HEATER = box_symbol('FTSs_heating_pad_12V', left=['+', '-'], ref='H')
PUMP = box_symbol('Penguin_XL_pump_24V', left=['+', '-'], ref='M')
PANPSW = box_symbol('MICRO_SWITCH_4A13BAA31', left=['C', 'NO', 'NC'], right=['LAMP5', 'LAMP2'], ref='SW')


# ---------------------------------------------------------------- helpers
def gl(s, pin, name, side='right', stub=4):
    """Stub wire from a pin and a global label at its end."""
    dx = g(stub) if side == 'right' else -g(stub)
    end = (pin[0] + dx, pin[1])
    s.wire(pin, end)
    s.glabel(end, name, rot=0 if side == 'right' else 180)
    return end


def down_to(s, pin, y, dx=0, junction=True):
    """Pin → short horizontal → vertical to row y; junction at the end."""
    x = pin[0] + g(dx)
    if dx:
        s.wire(pin, (x, pin[1]))
    s.wire((x, pin[1]), (x, g(y)))
    if junction:
        s.junction((x, g(y)))
    return (x, g(y))


def bend(s, a, b, xm):
    """a → (xm, a.y) → (xm, b.y) → b : a three-segment orthogonal wire."""
    s.wire(a, (xm, a[1])); s.wire((xm, a[1]), (xm, b[1])); s.wire((xm, b[1]), b)


def bendy(s, a, b, ym):
    """a → (a.x, ym) → (b.x, ym) → b."""
    s.wire(a, (a[0], ym)); s.wire((a[0], ym), (b[0], ym)); s.wire((b[0], ym), b)


def vres(s, res, x, ybot, ytop):
    """Return (bottom_pin, top_pin) of a vertical resistor placed at x between rows."""
    a, b = res['1'], res['2']
    return (a, b) if a[1] > b[1] else (b, a)


def header(s, title, sub=None):
    s.text(G(8, 8), title, size=1.6)
    if sub:
        s.text(G(8, 12), sub, size=1.27)
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

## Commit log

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2021-02-16 set ground pins and fix indentation
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2021-02-17 fix mash probe name
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2021-02-27 try to fix crash
    https://raspberrypi.stackexchange.com/questions/61621/sending-new-wave-to-pigpiod-causes-pi-to-lock-up
2021-03-14 added kicad files for led display
    [LED Display-B_Cu.gbr, LED Display-B_Mask.gbr, LED Display-B_Paste.gbr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]
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2021-08-06 rename prototypes
    [LED Display-B_Cu.gbr, LED Display-B_Mask.gbr, LED Display-B_Paste.gbr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]
2021-08-06 original version from lbussy
    [Keg Cop - Daisy Chain Screw.kicad_pcb, Keg Cop - Daisy Chain Screw.sch, Keg Cop - Main.kicad_pcb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]
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2021-08-08 ttgo plus seven chips
    [mph-pcb.kicad_pcb, mph-pcb.sch]
2021-08-08 based on mph
    [mph-pcb.kicad_pcb, mph-pcb.sch]
2021-08-08 fixed labels
    [mph-pcb.sch]
2021-08-08 removed old file
    [mph-pcb.kicad_pcb, mph-pcb.sch]
2021-08-08 cloned with https://github.com/bobc/KiRename
    [lower-pcb.kicad_pcb, lower-pcb.sch, rpm-pcb.kicad_pcb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]
2021-08-08 first four 7-segment displays
    [mph-pcb.sch]
2021-08-08 store all libraries in project
    [mph-pcb.sch]
2021-08-08 wire up a-f on displays
    [mph-pcb.sch]
2021-08-08 fixed footpads
    [mph-pcb.sch]
2021-08-08 add coupling capacitors
    [mph-pcb.sch]
2021-08-08 fixed missing footpads
    [mph-pcb.sch]
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2021-08-08 finished wiring
    [mph-pcb.sch]
2021-08-08 added mph leds
    [mph-pcb.sch]
2021-08-08 added title
    [mph-pcb.sch]
2021-08-08 added author
    [mph-pcb.sch]
2021-08-08 added msg tx
    [mph-pcb.sch]
2021-08-09 add blanking resistors
    [mph-pcb.sch]
2021-08-09 copied custom symbols
    [mph-pcb.sch]
2021-08-12 removed old copies
    [lower-pcb.kicad_pcb, lower-pcb.sch, rpm-pcb.kicad_pcb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]
2021-08-12 fixed typo
    [mph-pcb.sch]
2021-08-12 initial wiring
    [rpm-pcb.kicad_pcb, rpm-pcb.sch]
2021-08-12 finished initial wiring
    [rpm-pcb.sch]
2021-08-12 fixed for bug checker
    [rpm-pcb.sch]
2021-08-12 duplicated left side
    [rpm-pcb-left.sch]
2021-08-12 added right bar displays
    [rpm-pcb.sch]
2021-08-12 finished wiring and bug check
    [rpm-pcb.sch]
2021-08-12 removed temporary file
    [rpm-pcb-left.sch]
2021-08-12 created lower pcb and bug check
    [lower-pcb.kicad_pcb, lower-pcb.sch]
2021-08-12 fixed colors on bar displays
    [rpm-pcb.sch]
2021-08-12 fixed lib references
    [mph-pcb.sch]
2021-08-12 fixed red and green bars
    [lower-pcb.sch, rpm-pcb.sch]
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2021-08-17 sed to get flangeless led
    [mph-pcb.sch]
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2021-08-17 added footpads for light blocks and screw terminals
    [rpm-pcb.sch]
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2021-08-18 add 12 seg led footprints
    [lower-pcb.sch]
2021-08-18 added footpads
    [lower-pcb.sch]
2021-08-18 add footpad for logic level shifter
    [lower-pcb.sch, mph-pcb.sch, rpm-pcb.sch]
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2021-08-19 prototype layout
    [mph-pcb.kicad_pcb]
2021-08-19 add pegboard holes
    [mph-pcb.kicad_pcb]
2021-08-19 removed dummy components
    [mph-pcb.kicad_pcb]
2021-08-19 changed pegboard holes to m5
    [mph-pcb.kicad_pcb]
2021-08-19 initial placement
    [mph-pcb.kicad_pcb, mph-pcb.sch]
2021-08-19 finished placing leds
    [mph-pcb.kicad_pcb]
2021-08-19 place chips and resistors
    [mph-pcb.kicad_pcb]
2021-08-19 add net ties for coupling caps
    [mph-pcb.kicad_pcb, mph-pcb.sch]
2021-08-19 routed led display chips
    [mph-pcb.kicad_pcb, mph-pcb.sch]
2021-08-19 finshed mph placement
    [mph-pcb.kicad_pcb, mph-pcb.sch]
2021-08-19 fill zones
    [mph-pcb.kicad_pcb]
2021-08-20 more wiring
    [mph-pcb.kicad_pcb, mph-pcb.sch]
2021-08-20 finished wiring mph
    [mph-pcb.kicad_pcb]
2021-08-20 drc check
    [mph-pcb.kicad_pcb]
2021-08-20 fixed coupling caps and blank resistors
    [rpm-pcb.sch]
2021-08-20 fixed pegboard to 25mm spacing
    [mph-pcb.kicad_pcb]
2021-08-20 fixed pegboard spacing
    [mph-pcb.kicad_pcb]
2021-08-20 placed rpm leds
    [rpm-pcb.kicad_pcb, rpm-pcb.sch]
2021-08-20 added extra cg led
    [rpm-pcb.kicad_pcb, rpm-pcb.sch]
2021-08-20 reworked rpm leds
    [rpm-pcb.kicad_pcb]
2021-08-20 moved back from print position
    [rpm-pcb.kicad_pcb]
2021-08-20 reposition based on printout
    [rpm-pcb.kicad_pcb]
2021-08-20 check and measured rpm leds
    [rpm-pcb.kicad_pcb]
2021-08-21 fixed 12 seg leds
    [rpm-pcb.kicad_pcb, rpm-pcb.sch]
2021-08-21 220 tab down
    [rpm-pcb.kicad_pcb, rpm-pcb.sch]
2021-08-21 switch yellow leds to mosfets
    [mph-pcb.sch]
2021-08-22 changed for new optoelectronics
    [mph-pcb.kicad_pcb, mph-pcb.sch]
2021-08-22 get rid of some vias
    [mph-pcb.kicad_pcb, mph-pcb.sch]
2021-08-22 label components
    [mph-pcb.kicad_pcb]
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2021-08-24 fixed footprints for mph leds
    [mph-pcb.kicad_pcb, mph-pcb.sch]
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2021-08-29 add spiffs partition map
    [partitions.csv]
2021-08-29 copied from st7789
    [partitions.csv]
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2023-04-13 moved prototype code
    [Keg Cop - Daisy Chain Screw.kicad_pcb, Keg Cop - Daisy Chain Screw.sch, Keg Cop - Main.kicad_pcb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]
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2023-04-23 fixed lamps on boot
    [panp.py]
2023-04-23 fixed power on boot
    [panp.py]
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2023-04-29 fixed incorrect variable name and function call
    [panp.py]
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2023-04-30 fix handling of switchpod
    [panp.py]
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2023-05-06 fixed 50 on circle
    [panp.py]
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2023-07-23 fixed off by one error
    [panp.py]
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2024-03-03 fixed left switchpod
2024-03-03 restart switchpod on error
    [panp.py]
2025-02-09 fix red/green dummy 3
    [panp.py]
2026-09-13 fix database connection leak and switchpod queue refs
    close_database was misspelled as database_close, so the rpints MySQL
    connection was never closed and a new one was opened every tenth loop.
    Moved the close into a finally block so it also runs when the query
    itself throws.
    Both loop handlers read the module-level sp_q instead of self.sp_q,
    which only worked because they happen to be the same object.
    [panp.py]
2026-09-13 document the repository and the panp service
    Expand the top-level README from a stub, add kitt/README.md explaining
    panp.py, and correct the protocol notes in CLAUDE.md now that the KITT
    GLU spec and board firmware have been consulted: the third character of
    a packet is a register, not part of the command.
2026-09-13 document the dashboard and the switchpod interface
    Add kitt/DASHBOARD.md mapping KITT's season 2 labels to the brewery
    values behind them, with both switchpod layouts photographed, and
    kitt/switchpod/README.md describing the resistive ladder, the debounce,
    and the wire format.
    Note in the switchpod README that the extra newline emitted on every
    twentieth press desynchronises the Pi's two-byte reads and is what makes
    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
2026-09-13 fix switchpod dropout, drop stattosmith, port brewpitosmith
    get_switchpod treated the blank line the firmware emits on every
    twentieth press as an error, closing and reopening the port and going
    deaf for about three seconds each time. The blank-line skip was lost
    when the reopen was added in 1277428; restore it while keeping the
    reopen for input that genuinely cannot be parsed. Read with readline()
    rather than a fixed two bytes so a stray byte costs one keypress instead
    of desynchronising the stream until the next reopen.
    Remove stattosmith, which was for Brewer's Friend logs and unused.
    Port brewpitosmith to Python 3 and drop the numpy dependency. It now
    reads the log as real CSV, so the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
    [panp.py]
2026-09-13 correct the speedo bargraph and gravity scales
    The MPH bargraph is the speedo's 20-LED speed line driven with
    floor(temp/10), so it is one LED per 10 F, not 2 F as recorded. The
    gravity bargraph steps 0.004 SG per LED, not 0.0004, giving 1.000 to
    1.064 across the bar. Also note that the tacho seven-segment shows HI
    above 99.
    The 2 F figure came from the karr mockup, which labels a display that
    was never built.
2026-09-13 record that the protocol spec does not cover the tacho and speedo
    The v8 PDF leaves the tacho and speedo register tables blank because
    those registers did not exist when it was written; they were added to
    Paolo's firmware in 2023 so the host could drive those displays. For
    boards A and B the firmware parser is the authority, not the PDF.
2026-09-13 stop the switchpod firmware emitting a line wrap
    Paolo's example sketch separated keys with a space and wrapped the line
    every twentieth key so a serial monitor stayed readable. This sketch
    changed the separator to a newline, which turned that wrap into a stray
    empty line, and since the reopen-on-error handler landed the host has
    treated it as a parse failure and reset the port every twenty presses.
    Emit one key per line and nothing else. The host keeps skipping empty
    lines so an Arduino running older firmware still works.
    [main.cpp, panp.py]
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2026-09-13 archive karr and pi-temp-display
    Both describe hardware that never ran the brewery: karr was an ESP32 +
    TLC5940 rebuild of the dash electronics, shelved in 2023 when the
    ideegeniali boards arrived, and pi-temp-display is the seven-segment
    display the KITT dash replaced. Neither is maintained, and karr's
    mockups relabel the gauges differently from the running system, which
    invites exactly the confusion this removes.
    Tagged karr-prototype and pi-temp-display-final before removal, so both
    trees stay recoverable by name. The season 2 dash scan was moved out
    first; it documents the live hardware.
    [Keg Cop - Daisy Chain Screw.kicad_pcb, Keg Cop - Daisy Chain Screw.sch, Keg Cop - Main.kicad_pcb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]
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2026-09-13 back off when the switchpod adapter goes away
    A SerialException from readline hit the outer bare except and retried
    immediately, so an unplugged or re-enumerating adapter span the cpu at
    100% indefinitely: the reopen path only covered input that failed to
    parse. Treat both the same way, drop the port and wait for it to exist
    again before reopening.
    [panp.py]
2026-09-13 describe the boards' behaviour without quoting their firmware
    The eeprom notes named functions, source files and a part number read
    out of Paolo's firmware and schematic, which are confidential to him -
    and the undertaking given for them covers fragments as well as the
    whole. Nothing in this repo needs those identifiers: the rule a
    maintainer has to follow is that a message whose payload changes must
    not be sent repeatedly, and that stands on its own.
    Keep the behaviour, the consequence and the fix; point at the private
    repo for anything more specific.
2026-09-13 note that the tacho and speedo eeprom problem is fixed in firmware
    Fixed in the board firmware, but only on a board whose ATmega has been
    reflashed, so the note says to check rather than assume.
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2026-09-14 correct the bar colours: that is KITT's layout, not a brewery choice
    The previous wording had the causality backwards. It claimed the boards
    were picked so temperatures landed on red/green hardware and volumes on
    all red. They were not: the boards reproduce the season 2 dash, so the
    colours were fixed by the show, and both dummy3 variants exist because
    the car has one of each.
    The design ran the other way. The brewery was mapped onto the dash it
    found, and the counts line up - six tacho bars for six serving keezer
    probes, three red/green bars each for three lagering kegs and three
    fermenters, six all red bars for five serving kegs and a total.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
2026-09-15 correct the docs where they disagreed with the code
    Read the whole tree against panp.py and the systemd units and fixed the
    statements that did not hold:
    - panp.path fires when any of its PathExists conditions is met, not when
    all three are, so it does not wait for the switch pod adapter
    - the database is queried every eleventh pass, not every tenth
    - CAPACITY STATUS is the mean of five percentages, not a volume
    - the tacho falls a step at a time but rises at once; the dummies do
    neither
    - the switchpod reader uses readline(), which the same file already
    explained further down
    - pigpio is no longer imported
    Also recorded three things worth knowing before touching the code:
    the state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
2026-09-20 document the brewery hardware
    HARDWARE.md walks the whole physical system with the owner: the supply box
    and its fusing, the power button latch and interlocks, every relay module
    and barrier strip on the control panel, both pis' gpio and one-wire buses,
    all six unos, the dash boards, fermenters, chillers, keezers and flow
    meters, with a parts list and photographs in images/hw-*.jpg. corrects the
    power button description in kitt/README.md and DASHBOARD.md, and records
    the brewpi kitt-branch socket change and its state.
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2026-09-20 add kicad schematics of the control electronics
    four a3 sheets in schematics/, generated by ksheets.py through a small
    s-expression writer (kicadgen.py) from the wiring in HARDWARE.md: the
    supply box and power button, rpints, brewpi and the fermenters, and the
    panel distribution and dash. all four pass erc. rendered svgs in images/,
    linked from HARDWARE.md.
    [sheet1-power.kicad_sch, sheet2-rpints.kicad_sch, sheet3-brewpi.kicad_sch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]
2026-09-20 tidy panp.py without changing what it sends
    A behaviour-preserving rewrite, verified by driving the old and new
    scripts through the same scripted scenarios on both hosts under stub
    RPi.GPIO, serial, sdnotify and mysql modules and diffing every logged
    gpio call, serial byte, sleep and database call: 2357 events identical,
    plus the probe reader and the BrewPi socket poller checked separately.
    - serial ports are Bus objects with a per-port lock, so the GPIO
    callback thread and the main loop can no longer interleave packets;
    the sleep before each write stays at the call site
    - every bare except becomes except Exception, so SystemExit and
    KeyboardInterrupt are no longer swallowed on the wa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
    [panp.py]
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2026-09-20 let the main loop restore the caption when leaving auto
    set_auto_mode wrote the caption from the GPIO callback thread while the
    main loop could still be finishing a dark pass. Its trailing >CBa01? then
    landed after the caption and lapsed the override, so the message centre
    showed BREWPI UP over a correct value. Seen once on the dash and in strace
    after the serial gate made the two threads interleave.
    Mark the caption stale instead and let the loop send it on its first lit
    pass, after its own dark writes, so the order is fixed on one thread.
    [panp.py]
2026-09-20 keep the last good probe reading through a failed read
    The hot-side one-wire line hiccups for a second now and then and both
    probes on it come back empty together. read_probe_f turned that into 0.0,
    so the speedo painted 000 and 000.0 for a pass or two. Caught in strace
    at 00:15:59 tonight: two passes of zeros, then good values.
    Skip a failed read, and one that fails its CRC, so the display keeps the
    last good value; report 0.0 only after PROBE_MISSES failures in a row so
    a probe that has really gone still shows.
    [panp.py]
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2026-09-20 replace the drawn dash figures with photographs
    The dashboard guide illustrated each board with artwork cropped from the
    season 2 panel scan, which draws the wrong number of LEDs on the speedo.
    Replace the four figures with photographs of this dash, taken with panp
    stopped and every bar, LED and segment driven full at Norm brightness, and
    add one of the PANP keys. The tacho label is RPM on the hardware, not kRPM.
2026-09-20 correct the speedo led line step counts
    Measured on the board with panp stopped: the MPH line is 19 steps for
    20 leds and the multifunction line 13 steps for 16, not 16 and 16.
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2026-09-21 record what the dim speedo was and that both boards are reflashed
    The speedo's dimness was eeprom wear of its brightness byte, caused by
    the board firmware's odometer sharing those bytes, not heat. Both worn
    chips were dumped to prove it and the firmware layout is fixed. Note
    that leaving the dash lit is fine, and what still writes eeprom.
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
